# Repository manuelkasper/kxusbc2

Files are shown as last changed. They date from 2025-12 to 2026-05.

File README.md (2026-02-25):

# KXUSBC2 – Internal USB-C charger for the Elecraft KX2

## Introduction

Have you ever forgotten to bring your KX2 charger on a trip, accidentally torn the speaker wires after countless battery removals, or found yourself with a dead phone battery on a summit while the KX2 still had plenty of power? I’ve managed all three. Each time, I wished the KX2 simply had a USB-C port — no more removing the battery, no special charger to pack, and the ability to top up a phone.

External power banks are awkward when operating handheld with the AX1 and may cause QRM. The KXIBC2 option still requires a specific AC adapter, charges very slowly, and cannot supply power to a phone. Perhaps the best solution until now was to bypass the KX2's built-in reverse-power diodes and connect an external USB-C charger. But with all of these solutions, you can forget something at home that you can’t buy on the go.

I prefer fully integrated things that are simple and foolproof to use. So I set out to design an option PCB that installs in place of a KXIBC2 or KXIO2 and adds a bidirectional (dual-role) USB-C port for charging and discharging the internal battery. In homage to Elecraft’s naming convention for KX2 options, I call it the **KXUSBC2** — an unofficial option.

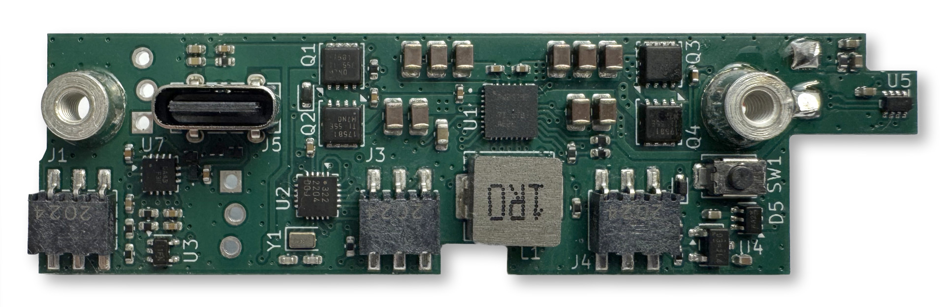
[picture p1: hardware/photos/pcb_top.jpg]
PCB top

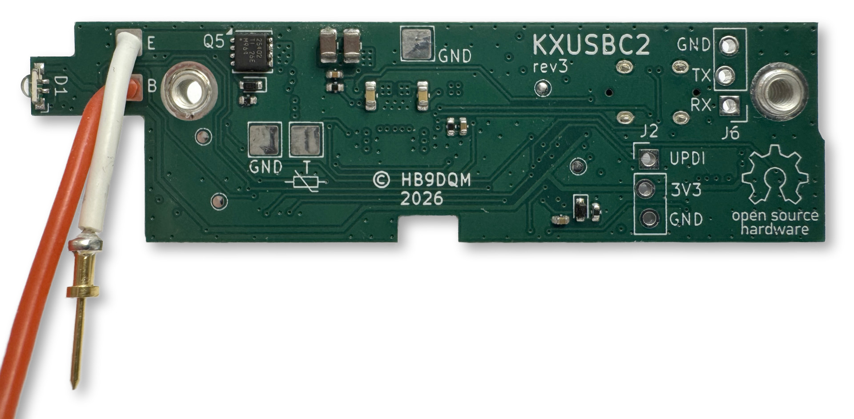
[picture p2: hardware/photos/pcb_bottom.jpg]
PCB bottom


Here is how it looks installed in a KX2, with a custom CNC-machined aluminum side plate for the USB-C port opening:

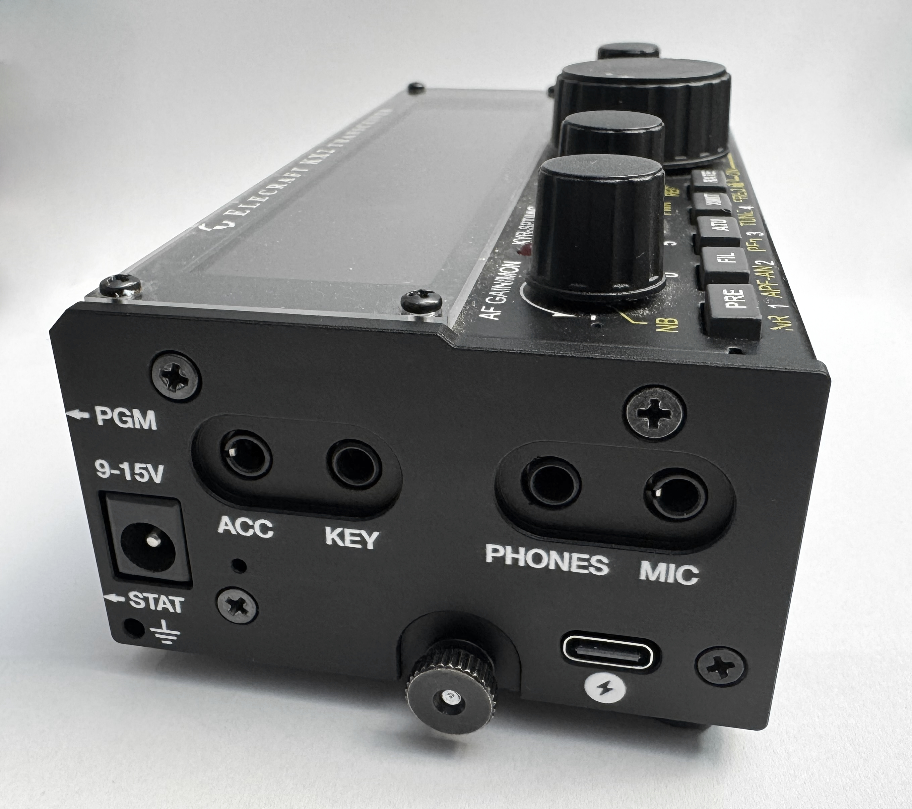
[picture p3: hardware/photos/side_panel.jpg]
KX2 replacement side panel with USB-C port


KXUSBC2 installed, side view

KXUSBC2 installed, top view

## Features

* Adds a bidirectional USB-C charging port to the KX2
* Charges the internal 3S Li-Ion battery at up to 30 W
* Dual-Role Port (DRP/OTG): Can also charge an external device (phone, GPS, HT etc.) through the same USB-C port at up to 30 W (5…15 V)
* Dual input: can charge from USB-C or DC jack
* Supports PD 3.0, QC, BC1.2
* Automatically suspends charging while KX2 is on
* Real-Time Clock (RTC)
* RGB status LED and config button
* Battery temperature monitoring (with thermistor, optional)
* Battery voltage monitor in KX2 menu (like KXIBC2)

## Tech details

* BQ25792 buck-boost battery charger IC
  * 1.5 MHz switching frequency
  * Quad external power MOSFETs for input switching
* FUSB302B USB-C controller
* ATtiny3226 microcontroller
  * Implements the PD protocol stack in firmware
  * Current/voltage limits etc. configurable in EEPROM
  * Config button for basic settings, trigger a PD role swap, reset
  * UPDI debug/programming header
  * Serial debug console header
* RTC emulated in MCU (SPI client), backed by crystal, with temperature compensation
* ~60 µA standby current
* 4-layer PCB
  * Components on both sides (min. 0402)
* Replacement aluminum side panel, CNC milled, anodized and silkscreen printed, with USB-C and button pin hole

For more information and a PDF schematic, see the [hardware notes](hardware/README.md).

## Installation

Installing the KXUSBC2 is quite simple, and similar to the procedure for the KXIBC2. See the [User Guide](USER_GUIDE.md) for details.

## Where to buy

While it is possible to have the board and side panel manufactured by a PCB/CNC service like JLC based solely on the design files in this repository, this is not economically viable at very small quantities due to the setup and overhead costs.

Online shops that sell the KXUSBC2 kit:

* [g7ufo.radio Shop](https://shop.g7ufo.radio/products/kxusbc2)

If you are interested in selling the KXUSBC2 in your shop and having it listed here, please contact me.

Another option (for people who have some experience ordering and working with PCBs) would be to do group buys, e.g. within a club/association. All information required to do this can be found in the [hardware documentation](hardware/README.md).

I am not selling the KXUSBC2 myself, so please do not send me emails with purchase enquiries.

## Firmware updates and configuration

There is a web-based programmer at https://manuelkasper.github.io/kxusbc2/programmer/ that can flash firmware updates and allows easy UI-based configuration of the various settings (current limits etc.). All that is required is a simple UPDI adapter (essentially a USB-to-Serial TTL level adapter) and a browser that supports the Web Serial API.

## Development

The schematic/PCB was designed with KiCad, and the firmware was written to be compiled with AVR-GCC. See the [hardware notes](hardware/README.md) and [firmware notes](firmware/README.md) for details.

## Current state of the project

The PCB has gone through three revisions and is now at rev3, which is considered to be production-ready. rev2 boards have been tested by seven beta testers around the world, and all have worked on first try. The firmware is considered to be complete. See the issues page for any open issues or ideas for future revisions.

### Disclaimer

You are using the KXUSBC2 at your own risk; I won't take responsibility if your KX2, phone, charger, battery, etc. get fried due to this board, your house burns down, or if you unexpectedly end up with an empty battery. You might lose your warranty on the KX2 by using this board.

Elecraft ® is a registered trademark of Elecraft, Inc. This project is not affiliated with or endorsed by Elecraft.

### License

© 2025-2026 Manuel Kasper HB9DQM (mk@neon1.net).

This source describes Open Hardware and is licensed under the CERN-OHL-W v2.

You may redistribute and modify this documentation and make products using it under the terms of the CERN-OHL-W v2 (https:/cern.ch/cern-ohl). This documentation is distributed WITHOUT ANY EXPRESS OR IMPLIED WARRANTY, INCLUDING OF MERCHANTABILITY, SATISFACTORY QUALITY AND FITNESS FOR A PARTICULAR PURPOSE. Please see the CERN-OHL-W v2 for applicable conditions.

Source location: https://github.com/manuelkasper/kxusbc2



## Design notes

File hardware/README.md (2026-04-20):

# Hardware notes

## Schematic

Designed with KiCad.

**[PDF version of the schematic](pcb/kxusbc2.pdf)** for quick viewing (may not be the most recent version).

## PCB

### Specifications

* 4 layers
* FR-4
* 1 mm thickness
* 1 oz copper on all layers (including internal)

The design around the BQ25792 with its inductor and capacitors follows the guidelines given in the datasheet, and takes the EVM design as a basis. However, due to space constraints and the oblong shape, some compromises in the PCB layout had to be made: the BQ25792 has been rotated 180° relative to the reference design, making the switching nodes slightly longer and closer to other traces. Care was taken to keep them isolated from other traces by intermediate ground plane layers.

### JLCPCB order settings

When ordering from JLCPCB, the files located in [pcb/jlcpcb/production_files](pcb/jlcpcb/production_files) can be uploaded directly. The following settings should be selected in the order process:

#### PCB

* Layers: 4
* Dimensions: 69 x 19 mm (will be increased automatically for edge rails)
* PCB Thickness: 1.0 mm
* Material: FR4
* Surface Finish: LeadFree HASL or ENIG
* Outer Copper Weight: 1 oz
* Inner Copper Weight: 1 oz (!)
* Via Covering: Plugged

#### PCB Assembly

* PCBA Type: Standard
* Assembly Side: Both Sides
* Edge Rails/Fiducials: Added by JLCPCB
* Depanel boards & edge rails before delivery: Yes

## Side panel

### Specifications

* Aluminum 6061
* Bead-blasted, hardcoat-anodized, and silkscreened

## Kit components

A full KXUSBC2 "kit" requires the following components:

* KXUSBC2 PCB, assembled on both sides
* Custom side panel
* 3 x Receptacle (unless assembled by PCB factory)
  * TE Connectivity 2307725-3
  * DigiKey [17-2307725-3CT-ND](https://www.digikey.com/en/products/detail/te-connectivity-amp-connectors/2307725-3/11503286)
* 2 x Standoff M2.5 3 mm height (unless assembled by PCB factory)
  * Würth Electronics 9774030151R
  * DigiKey [732-7083-1-ND](https://www.digikey.com/en/products/detail/würth-elektronik/9774030151R/5320626)
* Thermal pad 10x6 mm, 4 mm height
* Stranded silicone insulated wires, AWG 22, red/white 60 mm ea.
* 2 x Solder pin
  * Mill-Max 3132-0-00-15-00-00-08-0
  * DigiKey [ED90540-ND](https://www.digikey.com/en/products/detail/mill-max-manufacturing-corp/3132-0-00-15-00-00-08-0/413214)
* 2 x Solder receptacle
  * Mill-Max 8827-0-15-15-16-27-04-0
  * DigiKey [ED1304-ND](https://www.digikey.com/en/products/detail/mill-max-manufacturing-corp/8827-0-15-15-16-27-04-0/4440738)
* Heat shrink tube 2.5 x 15 mm
* Thermistor (optional)
  * NTC 10k
  * DigiKey [2259-RH18-6Y103FB-075-S-ND](https://www.digikey.com/en/products/detail/mitsubishi-materials-u-s-a-corporation/RH18-6Y103FB-075-S/14308046)

## Cost

Most of the parts are relatively low cost, and the board was designed so that it can be produced and assembled by low-cost services like JLCPCB, with almost all passive components from the “Basic” component selection, which doesn't incur component-loading fees. Most components are on the top side, but due to space constraints, some had to be placed on the bottom side as well. Traces, via holes etc. are fairly large to avoid precision PCB costs.

The total BOM at qty. 10 is around $30/pc. (including PCB production and assembly of both sides), plus $12/pc. for the CNC milled, anodized and silkscreen printed side panel.

## Efficiency

Conversion efficiency

The graph above is taken from the BQ25792's datasheet. I've done some casual measurements, both using the BQ25792's internal ADC and shunts, and with external power meters, and they agree with the data in the graph: around 95% when charging from 15 V input, and between 85% and 90% from 5 V (depending on the current). There seems to be no problem dissipating the maximum possible loss of around 3 W through the side panel (thermal pad placed between the IC and the panel), and in any case, the charger IC has thermal regulation and shutdown.

## Power connection to the KX2

Like the KXIBC2, the KXUSBC2 is intended to be wired to the “E” and “B” pads on the KX2 RF PCB (under the battery) for connection to the external DC jack and the internal battery jack, respectively. Refer to the [KXIBC2 manual](https://ftp.elecraft.com/KX2/Manuals%20Downloads/E740370-B5,%20KXIBC2%20manual.pdf) for details.

Wire lengths, measured from the pad on the KXUSBC2 to the tip of the connector pin attached to the wire: E 28 mm, B 40 mm.

Receptacle pins for soldering to the KX2 PCB, probably also used by Elecraft for factory installation: Mill-Max 8827-0-15-15-16-27-04-0. Mating pin for crimping or soldering to wire: Mill-Max 3132-0-00-15-00-00-08-0 (for 22-24 AWG).

The PCB trace resistance between the “B” pad on the RF PCB and the central pin on the internal battery connector was measured to be around 5 mΩ (4T/Kelvin measurement). So although the pad/trace was probably not intended for this much current, it should have no problems handling 3 A.

The ground connection is via a single header pin rated for 2 A only. However, the standoffs with which the board is mounted to the side panel are grounded too. The coating/anodizing of the side panel should be stripped on the backside around the mounting holes, and along the bottom part where it meets other metal case parts (like the original side panel). This will provide a low-impedance ground connection through the side panel. Mounted this way, the resistance between the GND pad near the top edge of the backside of the KXUSBC2 PCB and the shaft of the battery DC plug was measured to be around 10 mΩ (4T/Kelvin measurement).

## Supported battery types

The charger has been designed for 3S Li-Ion batteries with a charging voltage of 12.6 V and a capacity of around 3000 mAh. The charging/discharging current limits can be changed in the EEPROM if smaller or larger batteries are used. Always use batteries with built-in protection and balancing circuits.

### Using 4S LiFePO₄ batteries

It is also possible to use 4S LiFePO₄ batteries. The charging voltage limit needs to be adjusted in the EEPROM. It is recommended to stay a bit below the limit enforced by the battery's protection circuit. Otherwise, when this voltage is reached during charging, the BMS may react by disconnecting the battery, causing the charging voltage to overshoot. This will manifest itself in a fault condition (red blinking LED), as the charger will detect an over voltage event. Usually 14.2 V is a good upper limit (e.g. some EREMIT batteries cut off at 14.2 V or even slightly below that).

## RTC

Some people like to use the clock provided by the KXIO2/KXIBC2 options for logging. The RTC chip that Elecraft uses (PCF2123) is obsolete, and the successors use a different register mapping that would require modifications to the KX2 firmware. As the MCU has spare capacity, I opted to use its internal RTC instead, emulating the few SPI commands that the KX2 uses to read/write the time in firmware. The RTC is clocked by a 32.768 kHz crystal, and the microcontroller consumes extremely little power for keeping the clock running.

The firmware automatically applies a temperature compensation, and one can also calibrate the clock using the KX2's "RTC ADJ" menu as usual.

Unlike the KXIO2/KXIBC2, the KXUSBC2 does not include a supercapacitor to keep the clock running during short power outages while swapping the battery. Having the KXUSBC2 installed means that most people probably won't need to swap out the battery anymore.

The KX2 uses an SPI frequency of 1 MHz (mode 0), and the delay between asserting RTC_CS (active high) and the beginning of the SPI transmission is about 10 µs.

## Battery monitoring

The KXUSBC2 includes a similar circuit to the one on the KXIBC2 that allows the KX2 to display the actual battery voltage in the menu. It works by dividing down the battery voltage and buffering it with an op-amp before passing it to the microcontroller in the KX2. The “KXIBC2” menu option must be set to “NOR” in the KX2's configuration menu for this to work.

Of course, the KXUSBC2 itself knows all voltages and currents flowing through it precisely, but it has no way to display those values on the KX2's display, as we cannot modify the firmware.

## QRM

A charger like this is somewhat akin to a 10 W PA amplifying a 1.5 MHz square wave into a low-pass filter. Having that right inside a sensitive HF rig, and even electrically connected to it, one might expect QRM mayhem. I thought so too, and thus the firmware defaults to automatically suspending charging while the KX2 is on, so one can still use an external power supply to power the KX2 while operating, without any QRM from the charger.

I did some lab testing with a dummy load connected to the KX2. Result: while charging the KX2 at 28 W from a 15 V PD source, I noticed that the noise floor increased from S0 to around S1 on 80-10m (preamp on). The only really strong signal that I could find in amateur bands was the 9th harmonic of the switching frequency, which varied around 9 * 1.55 = 13.95 MHz and 9 * 1.58 = 14.22 MHz in my test (the charger IC uses an RC oscillator), resulting in S7 QRM in a range of about 10 kHz somewhere in the lower half of the 20m band. Results in reverse mode (charging an iPad at 28 W) were similar.

Not wanting my concoction to cause excessive spurious emissions through the KX2's antenna port, I had a look with a spectrum analyzer. I am by no means an expert in this domain, but according to ETSI EN 301 783 clause 5.2.3, the limit for spurious emissions at the antenna port of an amateur radio device in standby mode is -57 dBm in the frequency range of 0.15 to 1000 MHz.

#### Test conditions
KX2 in off mode (ATU set to bypass before turning off), internal 3S battery charged to around 80%. KX2 antenna port connected directly to spectrum analyzer with 0.5 m LMR 240 cable. Spectrum analyzer set to peak detector mode to capture the worst-case scenario (the standards document is not entirely clear about which detector to use).

### Charging at 5 V @ 2.2 A

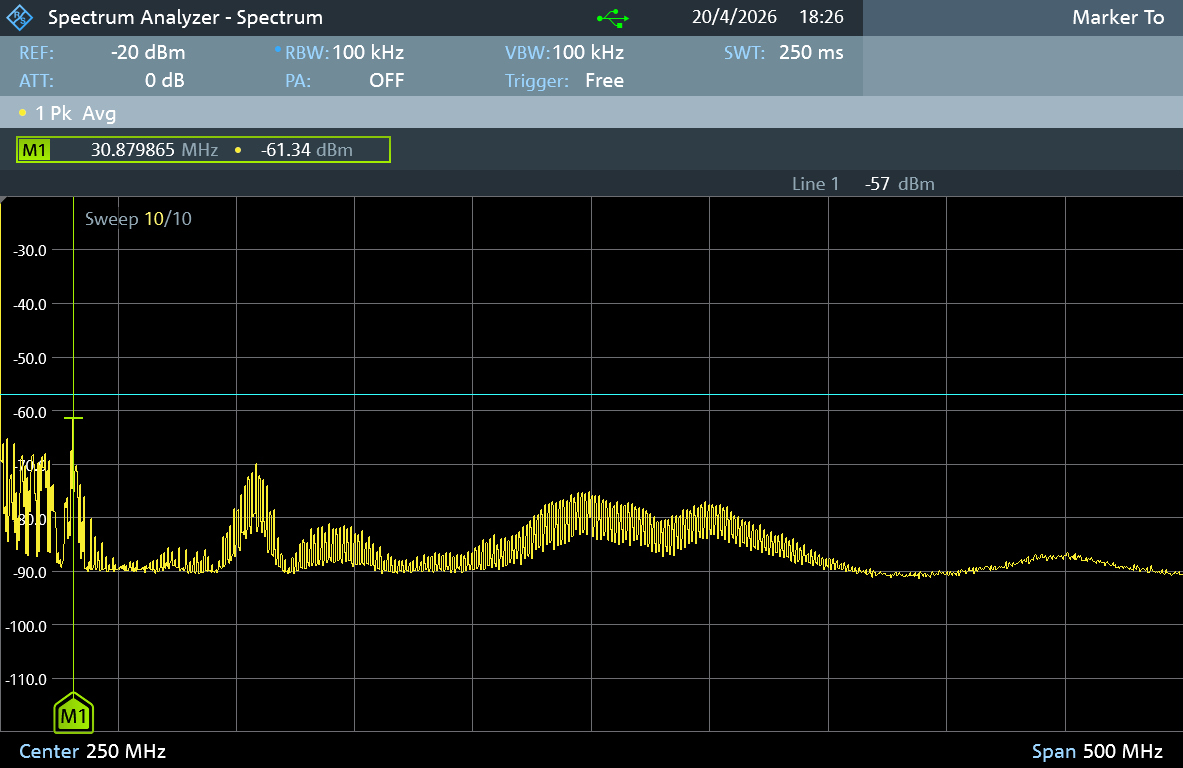
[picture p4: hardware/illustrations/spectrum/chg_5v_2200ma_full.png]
Full spectrum when charging at 5 V @ 2.2 A


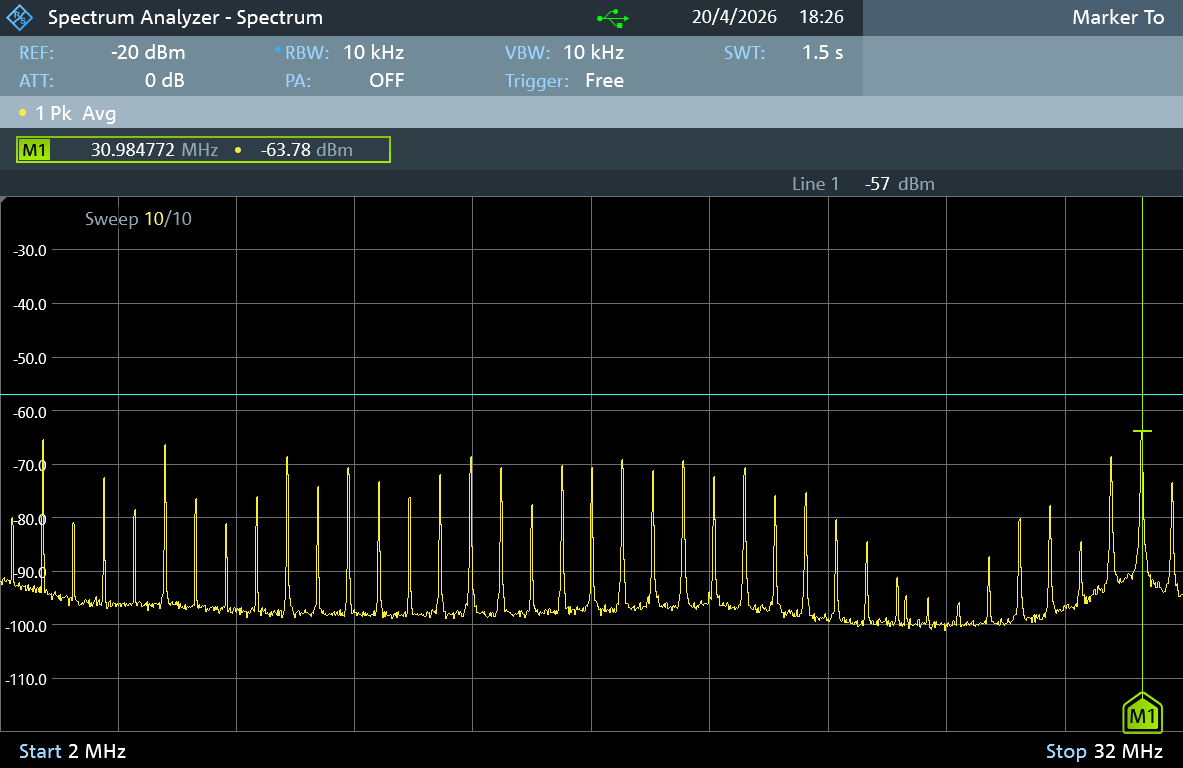
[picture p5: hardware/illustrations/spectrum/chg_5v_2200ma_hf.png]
HF spectrum when charging at 5 V @ 2.2 A


### Charging at 15 V @ 1.6 A

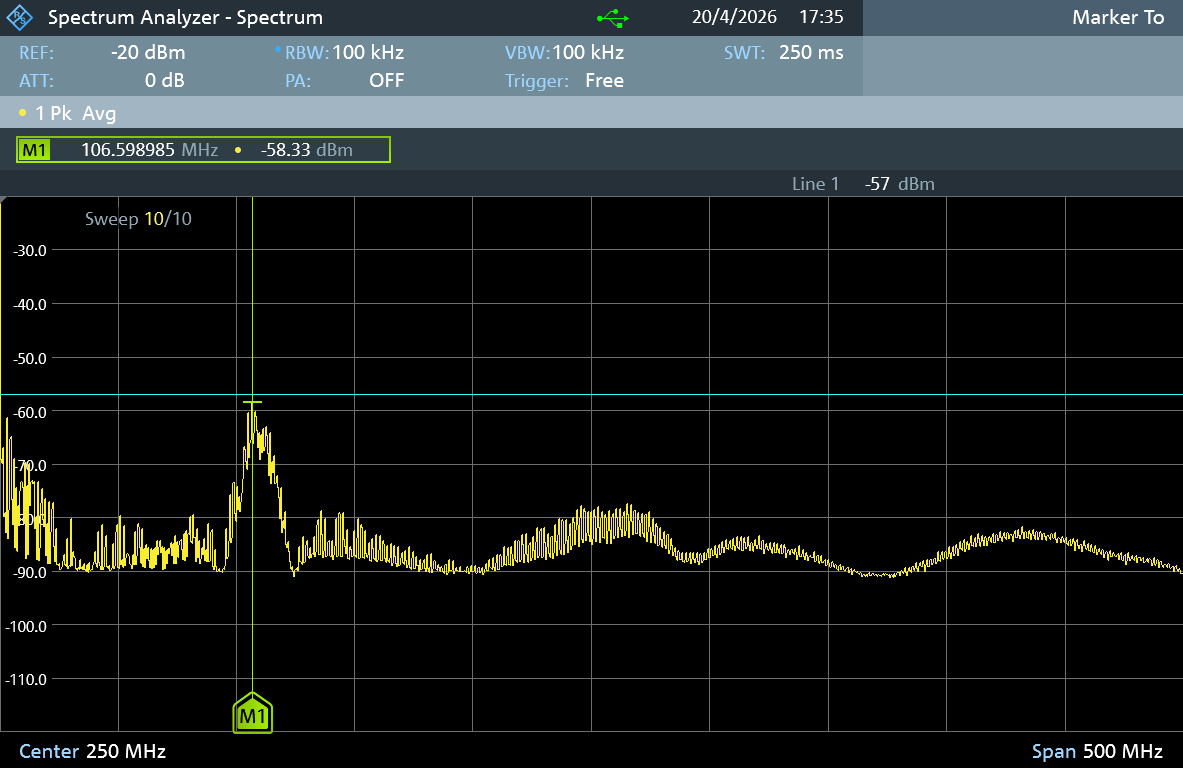
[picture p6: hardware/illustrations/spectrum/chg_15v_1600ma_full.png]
Full spectrum when charging at 15 V @ 1.6 A


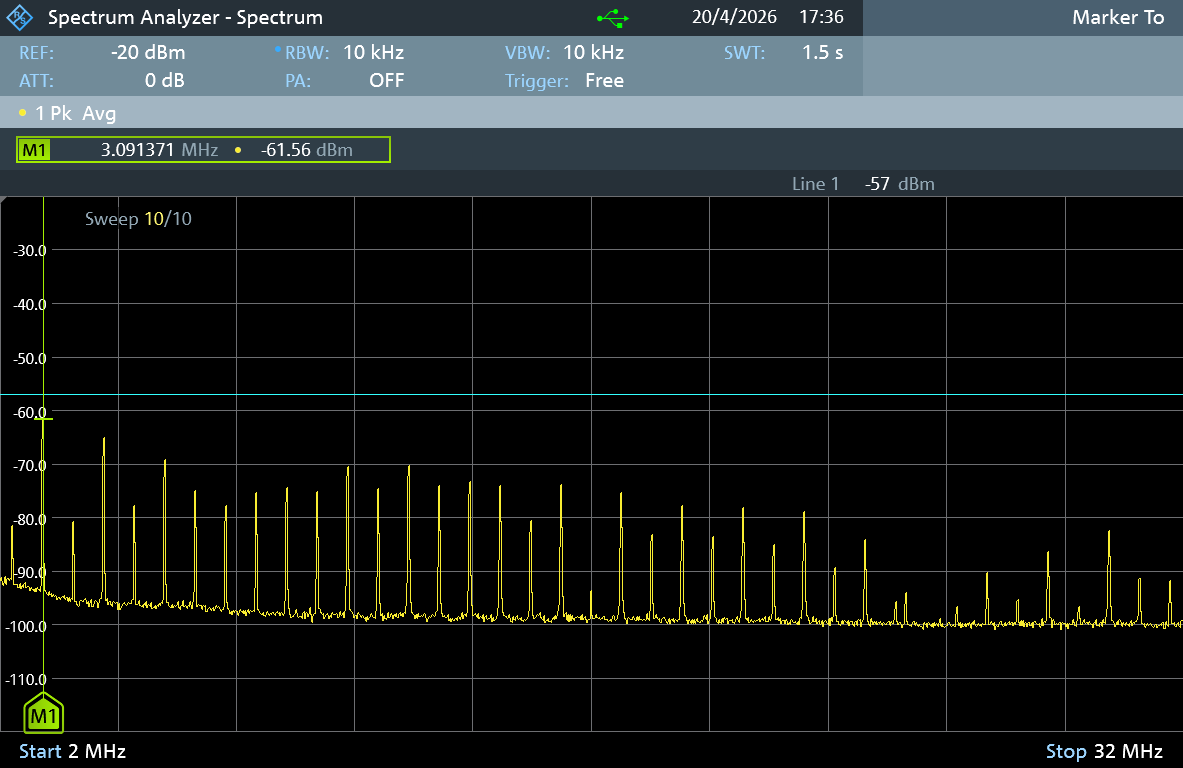
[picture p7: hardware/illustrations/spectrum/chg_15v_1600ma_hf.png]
HF spectrum when charging at 15 V @ 1.6 A


### Discharging at 5 V @ 3 A

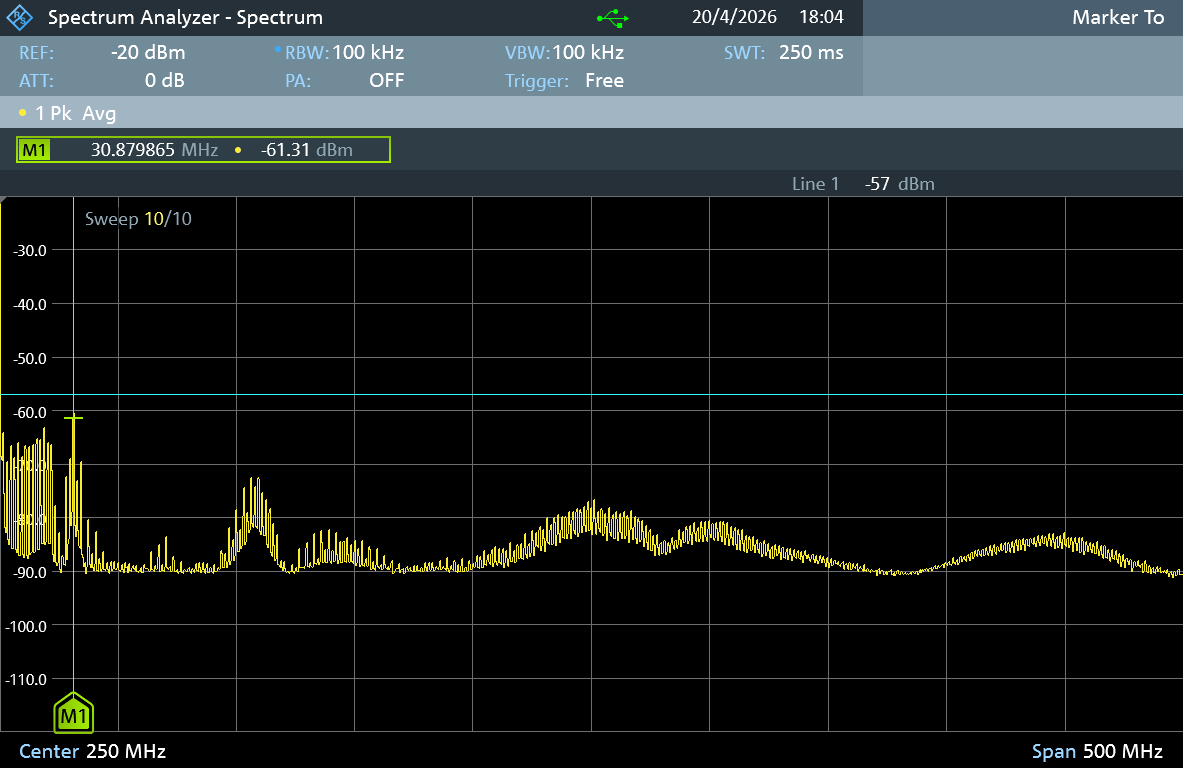
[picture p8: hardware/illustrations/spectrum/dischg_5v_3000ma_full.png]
Full spectrum when discharging at 5 V @ 3 A


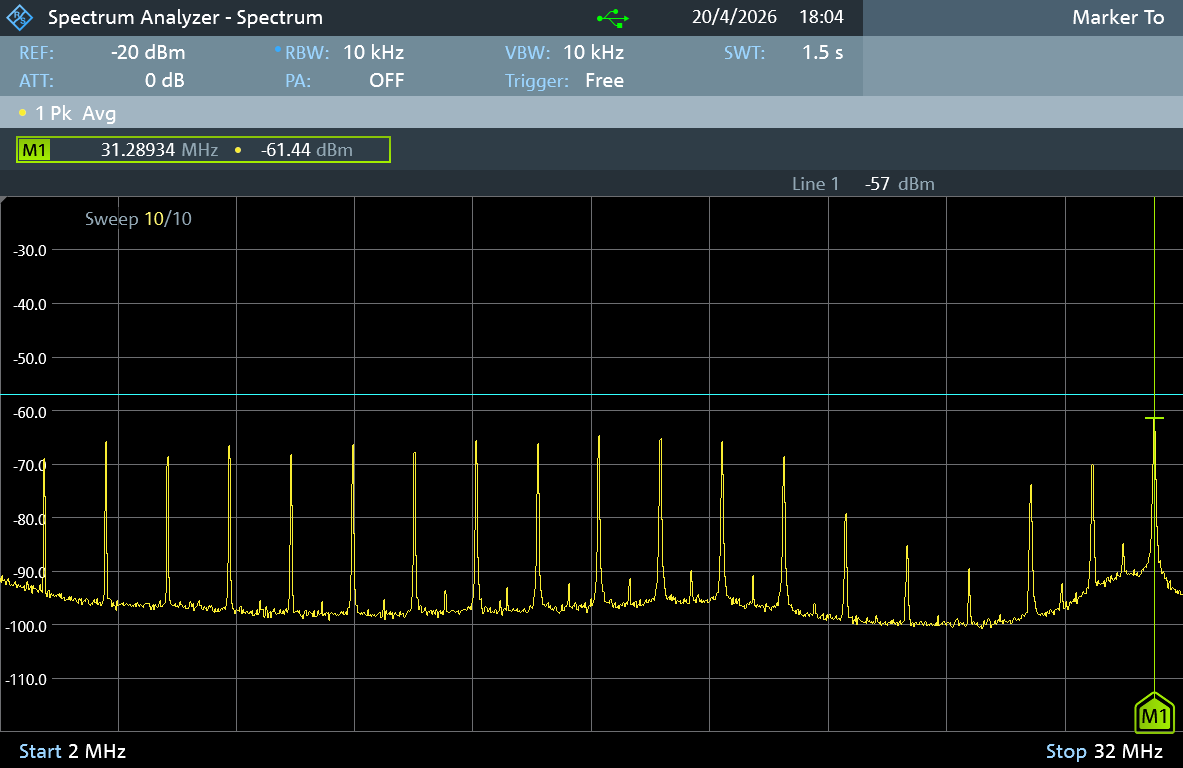
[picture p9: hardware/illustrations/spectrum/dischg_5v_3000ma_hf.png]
HF spectrum when discharging at 5 V @ 3 A


### Discharging at 9 V @ 3 A

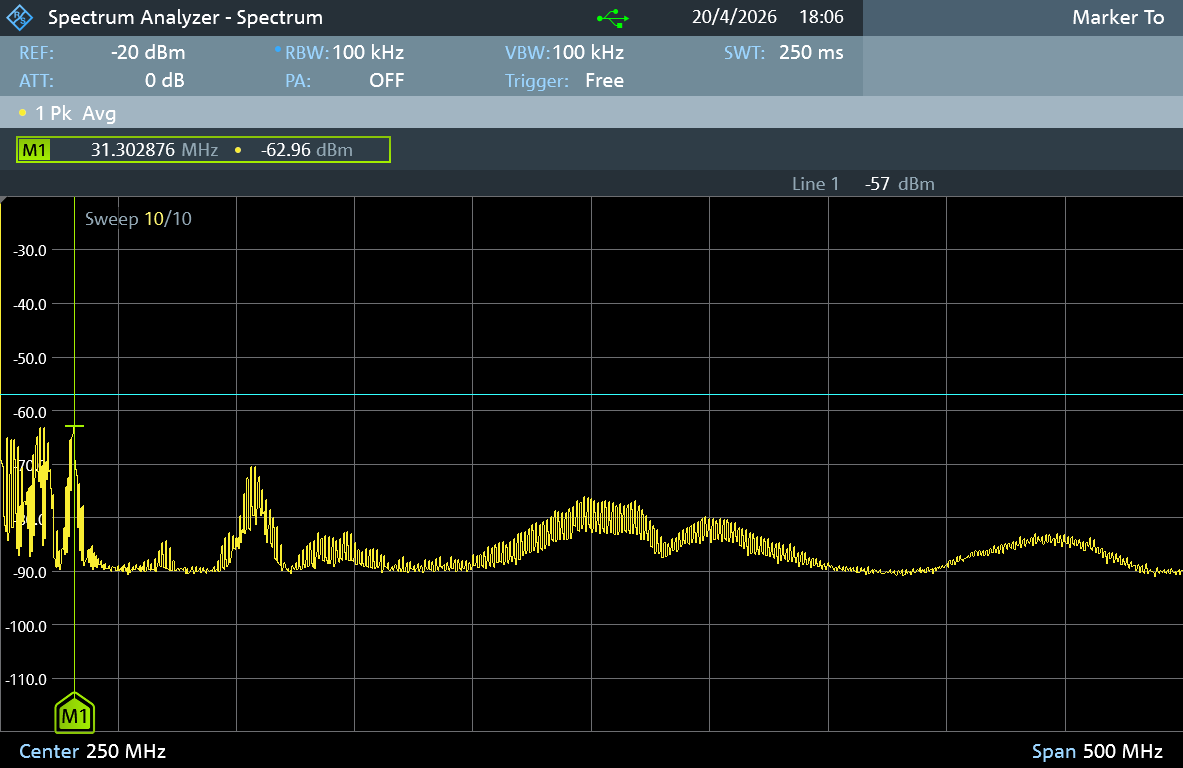
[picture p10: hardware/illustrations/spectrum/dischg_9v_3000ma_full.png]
Full spectrum when discharging at 9 V @ 3 A


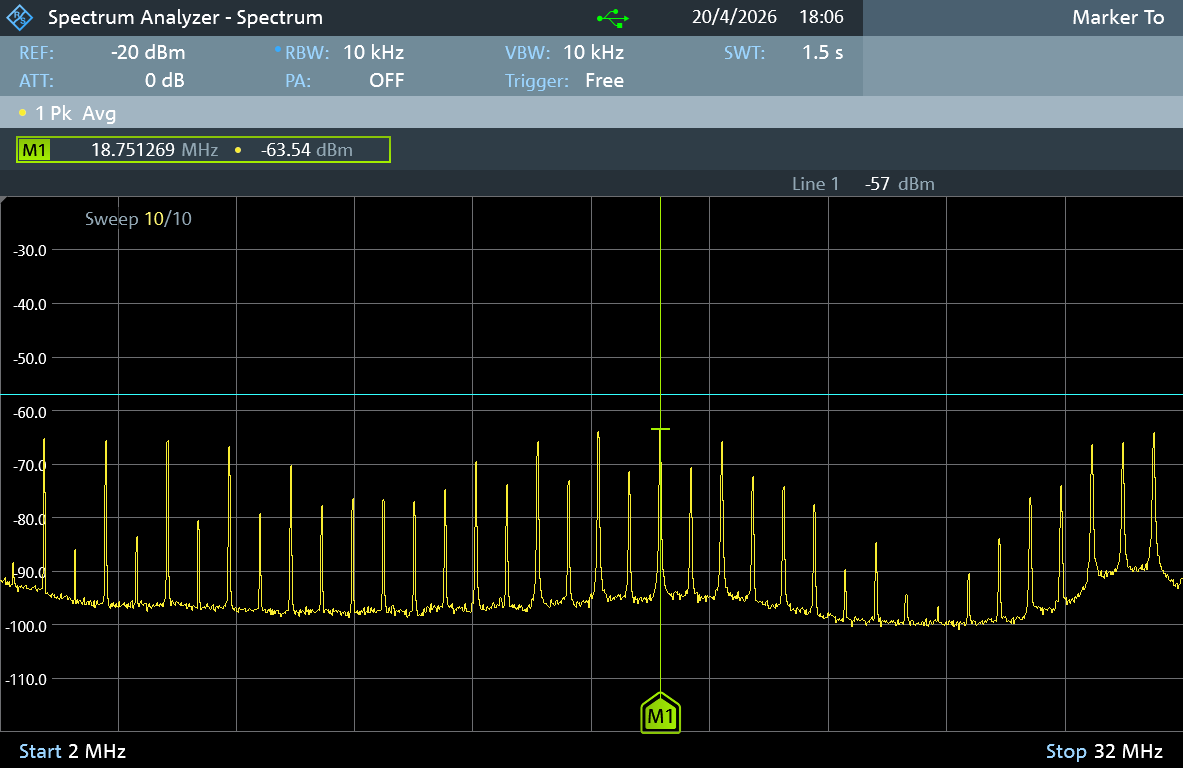
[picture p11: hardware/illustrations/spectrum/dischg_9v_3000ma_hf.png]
HF spectrum when discharging at 9 V @ 3 A


### Discharging at 12 V @ 2.5 A

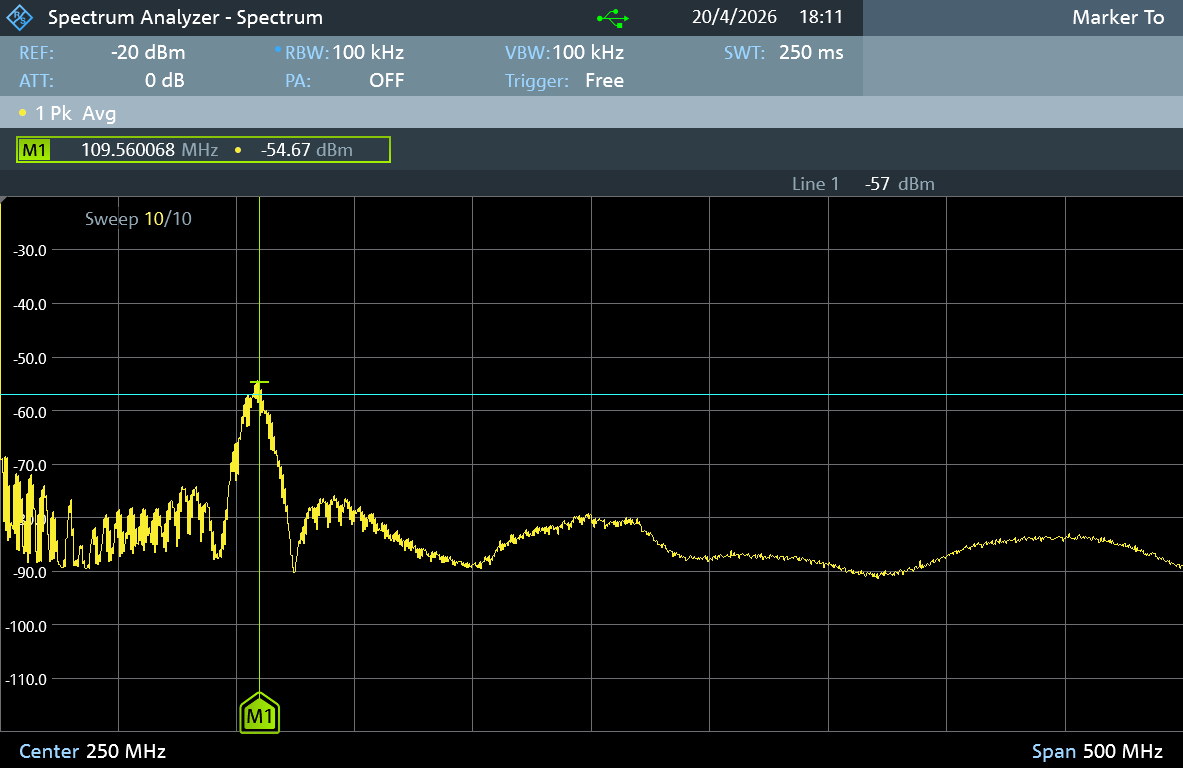
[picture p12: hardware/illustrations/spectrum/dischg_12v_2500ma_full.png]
Full spectrum when discharging at 12 V @ 2.5 A


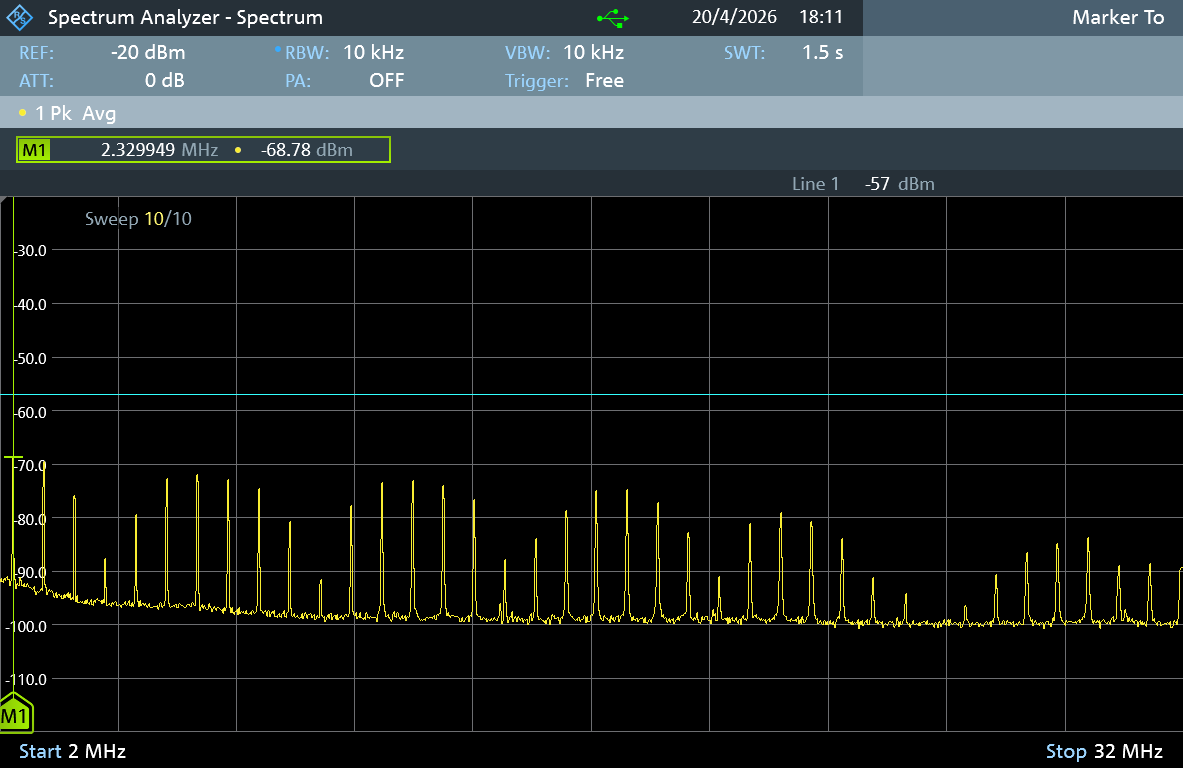
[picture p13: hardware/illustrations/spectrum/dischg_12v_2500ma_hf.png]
HF spectrum when discharging at 12 V @ 2.5 A


### Discharging at 15 V @ 2 A

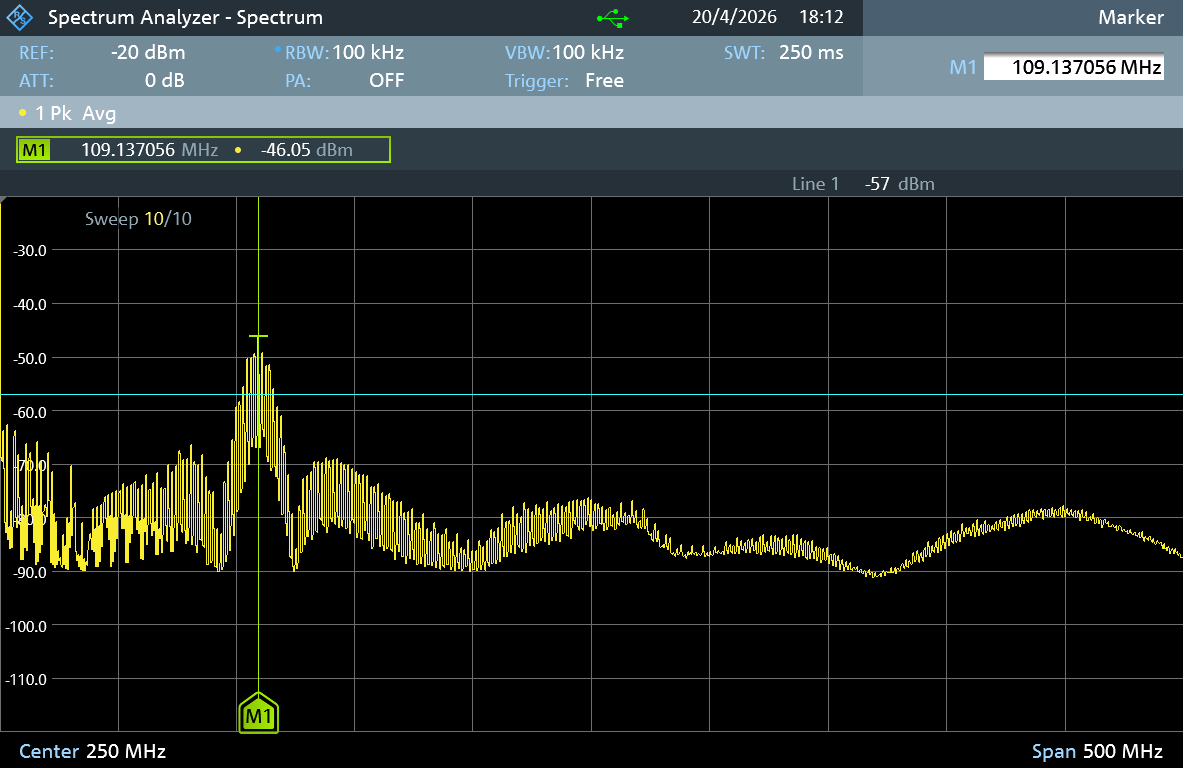
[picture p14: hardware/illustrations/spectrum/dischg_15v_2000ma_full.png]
Full spectrum when discharging at 15 V @ 2 A


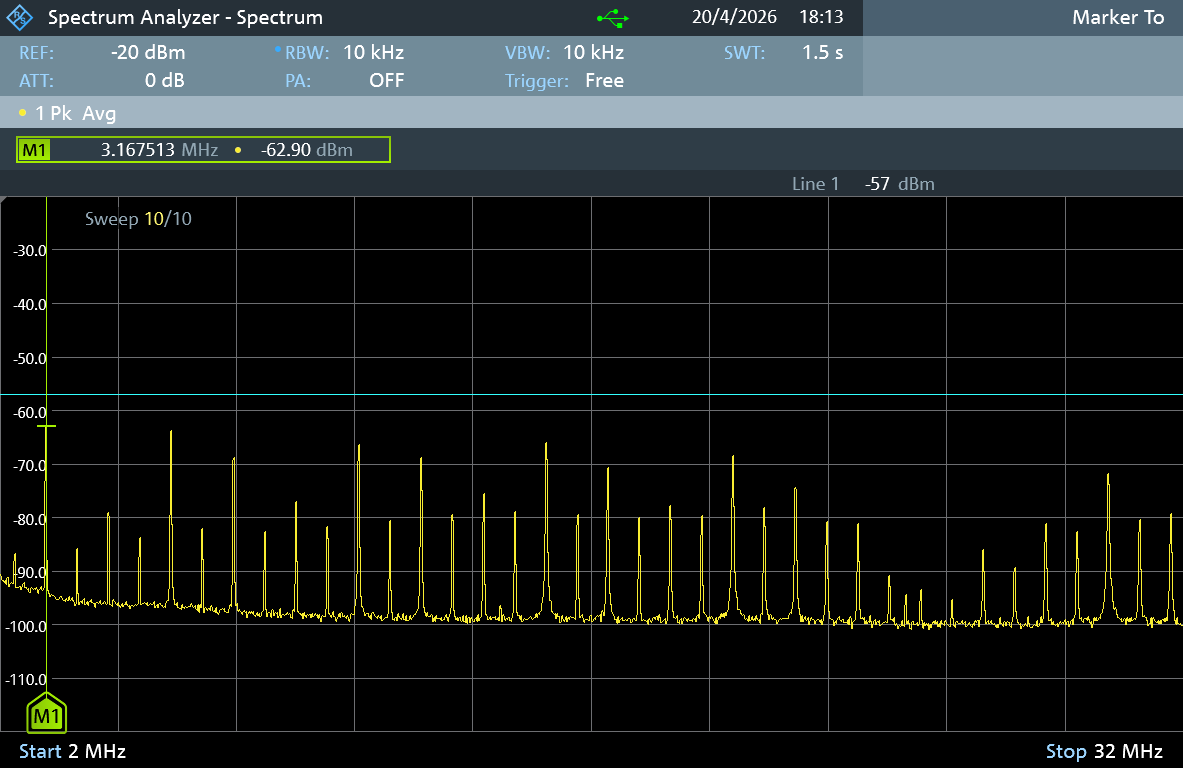
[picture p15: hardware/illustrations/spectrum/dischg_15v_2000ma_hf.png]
HF spectrum when discharging at 15 V @ 2 A


### Summary

When charging at typical power levels (15 V @ 1.6 A was the highest input current encountered during my tests with the maximum battery current set to the default of 2 A), the -57 dBm limit is respected, and also when discharging at typical voltages/currents for an attached smartphone. Only when discharging at both high voltages and high current (12 or 15 V at 2 A) are there spurs around 100 MHz that exceed the limit. It is thus recommended to disconnect the antenna from the KX2 when fast charging external devices. Alternatively, reducing the current to 1.5 A @ 12 V or 1 A @ 15 V also reduces those spurs to below the limit.

For comparison, here is the spectrum at the antenna port of a KX2 in RX mode (no KXUSBC2 installed) with the pre-amp on and the frequency set to 14.333 MHz:

### KX2 spectrum in RX mode (no KXUSBC2 installed)

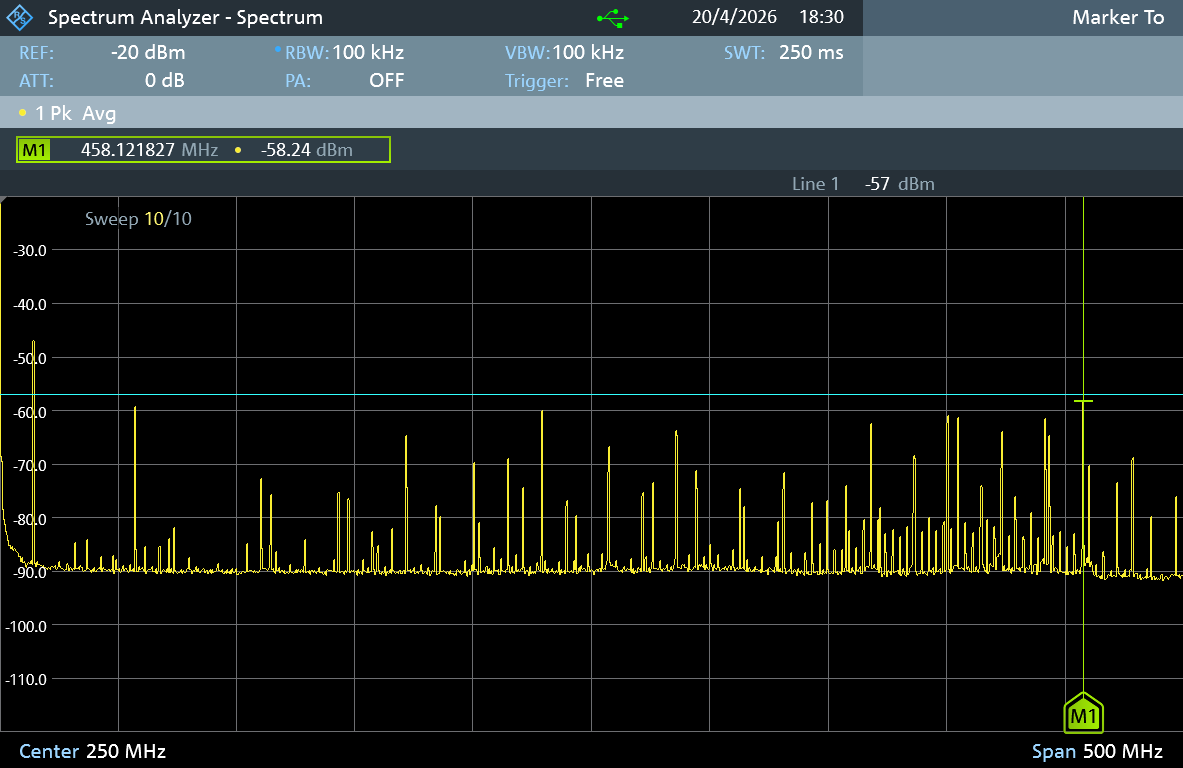
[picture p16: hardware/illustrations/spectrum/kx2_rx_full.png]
Full spectrum with KX2 in RX mode, without KXUSBC2 installed


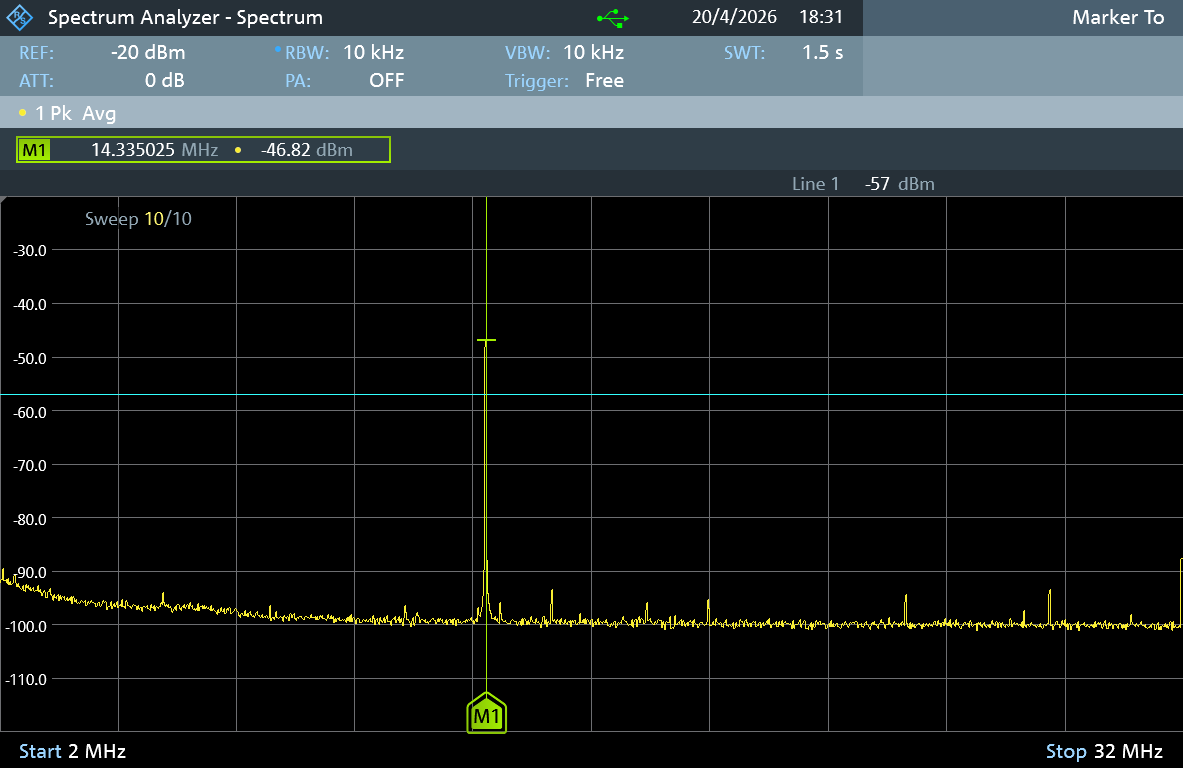
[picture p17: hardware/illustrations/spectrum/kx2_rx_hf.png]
HF spectrum with KX2 in RX mode, without KXUSBC2 installed


### Empirical test on summit with EFHW

Finally, to check the situation that interests the SOTA activator the most, I did a quick empirical test on a summit in a typical setup, with a 40/30/20m EFHW connected to the KX2 in SSB mode. Then I tried charging my iPhone at 10 W (9 V) from the KXUSBC2, and in a separate test, charging the KX2's battery from an external power bank at 18 W (12 V) while operating (auto-suspend feature disabled). In both cases, I could not discern a difference in noise floor on 80-20m, despite disconnecting/reconnecting the USB source/sink many times to find out. There were some spurious wandering signals around 14.310 MHz that I could trace to the charger, probably the 9th harmonic mentioned above, which was even higher now because it was cold on the summit.

Needless to say, it is not recommended to transmit while charging (as the PA drawing current from the charger may lead to increased TX noise/spurs), and by default, this situation is not possible anyway.

So to sum it up: QRM doesn't seem to be a big issue, even if you're charging while operating. And when not charging, the switching converter is completely off, so no QRM.

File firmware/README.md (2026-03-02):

# Firmware notes

The firmware is designed to be built with AVR-GCC.

Prerequisites:

* AVR-GCC toolchain (version 15.2.0)
* AVRDUDE (for programming)

## Build instructions

1. Download release v4.1.2 of the FUSB302 reference code from onsemi (login required): https://www.onsemi.com/design/evaluation-board/FUSB302BGEVB
2. Place the downloaded file `FUSB302 REFERENCE CODE.ZIP` in the root directory of the repository.
3. `sh merge_fsc_pd.sh`
4. Edit `Makefile` and set `PROGRAMMER` and `PORT` as needed.
5. `make` to compile the code.
6. `make flash` to flash the AVR.
7. `make eeprom` to write the default sysconfig settings to the EEPROM.
8. `make fuses` to program the fuses.

`DEBUG` should be set to 0 for release builds, otherwise standby consumption will increase (periodic debug status output, charger ADC active for measurements etc.). Also note that the PD protocol has quite strict timing requirements, and debug code/output can interfere with that and cause problems during PD negotiation, usually manifesting themselves as hard reset loops.

### Recommended fuse settings

The following settings are applied with `make fuses`:

* BOD level: 2.6 V
* Sample frequency: 1 kHz
* BOD mode in active: sampled
* BOD mode in sleep: sampled

#### AVRDUDE config

```
config bodsleep=bod_sampled
config bodactive=bod_sampled
config bodsampfreq=bod_1khz
config bodlevel=bod_2v6
```

## USB PD support

USB Power Delivery (PD) is a pretty complex specification/protocol that involves sending messages between the source and the sink (over the CC lines of the USB-C connector) to exchange capabilities and negotiate a power profile. Implementing a PD protocol stack from scratch for a DRP (Dual Role Port) would be a major undertaking. With some optimizations, I have succeeded in squeezing the reference code supplied by onsemi (makers of the FUSB302B IC) into the 32 KB flash of the ATtiny3226, and making it work.

The downside is that due to the license, while the reference code may be used freely in conjunction with onsemi chips, it cannot be redistributed. Therefore, this repository does not include the complete firmware source code, and requires downloading the reference code from onsemi and applying a patch with my optimizations before the firmware can be compiled (see instructions above).

### Modifications to the onsemi reference code
The patch included in the repository, `fsc_pd.patch`, which is applied automatically by `merge_fsc_pd.sh`, makes the following changes to the reference code:

- Replaced `FSC_U32` with `FSC_U16` or `FSC_U8` where bigger values would never be used anyway. As the AVR is an 8-bit device, operations with larger integers are expensive in terms of code size, memory usage and execution speed, especially if multiplication or division are involved.
    - This shaves around 1700 bytes from the compiled code size.
- When PD 3.0 support is enabled, devices that send a “Get Source Capabilities Extended” message trigger a hardware bug in the FUSB302B, which doesn't automatically send a GoodCRC for this particular message type.
    - Devices that send such messages then run into a timeout because they don't get the expected GoodCRC, and a hard reset loop ensues.
    - The onsemi reference code has a software workaround for this, enabled by the `FSC_GSCE_FIX` define. It works by sending a manual GoodCRC in software for such messages. As the GoodCRC timeout is 1 ms (tReceive), this has to happen fast.
    - However, there is also a bug in the code enabled by `FSC_GSCE_FIX`. Specifically, it uses the `I_CRC_CHK` interrupt instead of the normal `I_GCRCSENT` to trigger receiving a packet in `PDProtocol.c:ProtocolIdle()`. The latter can also be called from `ProtocolSendingMessage()`, but before making that call, `ProtocolSendingMessage()` already checks if `I_TXSENT` or `I_CRC_CHK` are set, and if either of them is, then it also clears `I_CRC_CHK`. This causes `ProtocolIdle()` to miss the incoming packet, which will only be processed when the next packet comes in – usually too late, so timers expire and hard resets are made. The usual case where this is triggered is when the PD source rejects a request, and doesn't send any further packets. Then the tSenderResponse timeout kicks in, the code issues a hard reset, and this loops forever.
    - The patch comments out the clearing of the `I_CRC_CHK` bit, which does not appear to have negative consequences.
- Increased tSenderResponse to 32 ms (USB PD ECN “Chunking Timing Issue”).
- Fixed case-sensitivity issue in `Port.c`: the onsemi code includes `"fusb30x.h"` but the actual filename is `fusb30X.h`. This had caused compilation to fail on case-sensitive filesystems (Linux).
- Set `TOG_SAVE_PWR` to 3 to reduce standby power consumption.

## Programming/Debugging

The ATtiny3226 has a one-wire UPDI interface for programming and debugging. The KXUSBC2 board provides this on a 3-pin 2.54 mm header on the backside, along with Vcc (3.3 V) and GND. The header doesn't actually need to be soldered – the middle pad is slightly offset/staggered, so one can get a good-enough interference fit by simply sticking a pin header through the holes for a temporary connection to the debugger. Call it a poor man's (or hobbyist-friendly) Tag-Connect 😂 This can be used directly with a NanoUPDI or a UPDI Friend, thus providing a programming solution for less than $10.

There is also a serial interface on a separate 3-pin header (also staggered), wired to the MCU's hardware USART, as UPDI does not support debug console output. Note that the levels there are 3.3 V, not RS-232.

Aside from command line tools like AVRDUDE that can be used to program the firmware and EEPROM, there is also a web-based programmer at https://manuelkasper.github.io/kxusbc2/programmer/ that can flash firmware updates and allows UI-based configuration of the various settings.

## Configuration

The following settings can be set in the EEPROM (see also the definitions in https://github.com/manuelkasper/kxusbc2/blob/main/firmware/src/sysconfig.h):

| Byte offset | Description | Type | Default | Range |
|:---|:---|:-----|:---|:---|
| 0 | Magic value (to detect erased EEPROM) | `uint16` | 0x4355
| 2 | Role | Enum<ul><li>0: SRC</li><li>1: SNK</li><li>2: DRP</li><li>3: TRY_SRC</li><li>4: TRY_SNK</li></ul> | 2: DRP
| 3 | PD mode | Enum<ul><li>0: Off</li><li>1: PD 2.0</li><li>2: PD 3.0</li></ul> | 2: PD 3.0
| 4 | Charging current limit (mA, max. current into battery) | `uint16` | 2000 | 50…5000
| 6 | Charging voltage limit (mV, termination voltage for CV phase) | `uint16` | 12600 | 10000…18800
| 8 | DC input current limit (mA, from DC jack) | `uint16` | 3000 | 100…3300
| 10 | OTG current limit (mA, output to USB) | `uint16` | 3000 | 120…3320
| 12 | Discharging voltage limit (mV, minimum battery voltage for OTG mode) | `uint16` | 9000 |
| 14 | OTG voltage headroom (mV, will be added to output voltage) | `uint16` | 100 | 0…500
| 16 | Allow charging while rig is on | `bool` | 0
| 17 | Enable thermistor | `bool` | 0
| 18 | User RTC offset (ppm, set in KX2 RTC ADJ menu) | `int16` | 0 | -278…+273

**Note that the AVR is a little endian platform**, e.g. the value 3000 would be represented as 0xB80B in EEPROM.

The OTG voltage headroom can be used to compensate for losses in the MOSFETs, PCB traces, cable etc.

### User Row

The MCU has a special EEPROM section called User Row, which is not erased in case of a Chip Erase command. This is different from the normal EEPROM, which is erased, unless the EESAVE fuse is programmed.

The User Row is currently used to store a factory-calibrated RTC offset, so that it is not inadvertently erased.

| Byte offset | Description | Type | Default | Range |
|:---|:---|:-----|:---|:---|
| 0 | Magic value (to detect erased User Row) | `uint16` | 0x5255
| 2 | Factory RTC offset (ppm) | `int8` | 0 | -127…127

## RTC emulation

The firmware acts as an SPI slave/client, emulating PCF2123-style registers to the KX2 firmware. Only the set of registers actually used by the KX2 firmware is implemented. The RTC peripheral of the MCU is clocked by an external 32.768 kHz crystal.

A fixed offset (in ppm) can be programmed in the User Row of the MCU to factory calibrate each board.

The KX2 has an "RTC ADJ" menu that lets the user compensate for a clock being too slow or too fast, by setting the number of seconds per day to compensate. The KX2 firmware translates this into a correction value for the PCF2123. The RTC emulation in the KXUSBC2 firmware calculates the equivalent ppm correction (4.34 ppm per unit according to the PCF2123 datasheet, in the "course mode" that the KX2 uses). The value set in the KX2 menu is stored in the EEPROM of the KXUSBC2 so that it is available after a restart, as the KX2 only sends the value when the user changes it.

The RTC emulation also features a temperature compensation. Once a minute, it measures the temperature using the MCU's built-in sensor and calculates an offset according to the temperature coefficient and turnover temperature given in the crystal's datasheet.

The offsets (factory, user and temperature) are added up before being applied to the `RTC.CALIB` register of the ATtiny3226. Positive offsets make the clock run slower, while negative offsets make it run faster. The maximum correction that can be applied in this way is ±127 ppm (about 11 seconds per day). Larger values will be clamped to this range.

## Input priority

The charger uses either the external DC jack input (E pad), or USB, whichever is connected first. If both sources are connected when the charger starts up, it prefers the DC jack input. The charger keeps using the current source as long as it is available, even if another source becomes available. However, if the current source disconnects, the charger switches. For example, if you connect a DC supply while the charger is charging from USB, it will keep using USB. If you then disconnect USB, it will seamlessly switch over to the DC jack input.

## Charge inhibit when rig is on

By default, the firmware suspends charging while the KX2 is on, to avoid any possibility of QRM. This is especially convenient when operating with an external DC power supply at home. Charging resumes as soon as the rig is turned off. Discharging is always possible, even when the rig is on, as the operator can always decide whether or not to plug in a USB-C device to be charged.

The setting can be changed in the EEPROM such that charging is always allowed, regardless of whether the KX2 is on or not.

## LED indications

| State | Color | Style |
|:---|:---|:---|
| Disconnected | off
| Negotiating | green / yellow (*) | blinking 5 Hz
| Charging | green / yellow (*) | pulsing frequency depending on charge current
| Charged | green | steady
| Temperature too high/low | red | steady
| Fault (over-voltage/current, short circuit etc.) | red | blinking 5 Hz
| Fault (battery voltage too low in OTG mode) | red | blinking 2 Hz
| Fault (charger init) | red | 3 x blinking at 2 Hz, followed by 1 s pause
| Fault (EEPROM) | red | 4 x blinking at 2 Hz, followed by 1 s pause
| Rig on (charging inhibited) | magenta | steady
| Discharging (OTG) | blue / cyan (*) | pulsing frequency depending on discharge current

If the thermistor is enabled and the temperature is in the “warm” or ”cool” region (where the current is reduced, but charging continues), the color is yellow (or cyan) instead of green (or blue).

### Charge/discharge speed indication

The LED will pulse faster the higher the current into or from the battery is.

| Battery current | LED pulsing frequency |
|:---|:---|
| < 500 mA | 8.5 s
| 500..999 mA | 2.5 s
| 1000..1999 mA | 1.2 s
| ≥ 2000 mA | 0.8 s

### Low battery during discharge

If the battery voltage drops below the discharging voltage limit set in the EEPROM, discharging will stop, and the LED will blink red. Further attempts to discharge (by disconnecting and reconnecting a sink) will not initiate discharging again, even if the battery voltage has recovered a little in the meantime. The battery must first be recharged, at least for a short time, before discharging is allowed again.

## Button functions

At this time, the following functions are implemented:

* Short press (< 1 second): attempt a PD role swap
  * Can be used, for example, to charge the KX2 from a smartphone that can act as a source (e.g. iPhone)
* Medium press (1…3 seconds): enter config menu (see below)
* Long press (> 3 seconds): system reset

### Config menu

Pressing the button for 1…3 seconds when nothing is connected to the KXUSBC2 (i.e. the LED is off) enters the config menu.

* While in the menu, the LED blinks yellow at 1 second intervals. The number of blinks indicates the current menu item.
* Short pressing advances to the next menu item.
* Medium pressing enters the currently blinking menu item.
  * The LED then blinks blue to show the current setting of the selected menu item.
  * Short pressing changes the setting.
  * Medium pressing leaves the menu item.
* Long pressing leaves the menu and restarts the system with the new settings.

| Menu item # | Description |
|:---|:---|
| 1 | Charging current limit
| 2 | DC input current limit
| 3 | Charge while rig is on
| 4 | Thermistor

#### Menu item 1: Charging current limit

| Value # | Description |
|:---|:---|
| 1 | 500 mA
| 2 | 1000 mA
| 3 | 2000 mA
| 4 | 3000 mA

#### Menu item 2: DC input current limit

| Value # | Description |
|:---|:---|
| 1 | 500 mA
| 2 | 1000 mA
| 3 | 2000 mA
| 4 | 3000 mA

#### Menu item 3: Charge while rig is on

| Value # | Description |
|:---|:---|
| 1 | disable
| 2 | enable

#### Menu item 4: Thermistor

| Value # | Description |
|:---|:---|
| 1 | disable
| 2 | enable

## Connection states

Enum values used by the FSC PD reference code, listed here for convenience to aid in debugging.

| Enum Value | Number |
|:---|---|
| Disabled | 0 |
| ErrorRecovery | 1 |
| **Unattached** | 2 |
| AttachWaitSink | 3 |
| **AttachedSink** | 4 |
| AttachWaitSource | 5 |
| **AttachedSource** | 6 |
| TrySource | 7 |
| TryWaitSink | 8 |
| TrySink | 9 |
| TryWaitSource | 10 |
| AudioAccessory | 11 |
| DebugAccessorySource  | 12 |
| AttachWaitAccessory | 13 |
| PoweredAccessory | 14 |
| UnsupportedAccessory  | 15 |
| DelayUnattached | 16 |
| UnattachedSource | 17 |
| DebugAccessorySink | 18 |
| AttachWaitDebSink | 19 |
| AttachedDebSink | 20 |
| AttachWaitDebSource | 21 |
| AttachedDebSource | 22 |
| TryDebSource | 23 |
| TryWaitDebSink | 24 |
| UnattachedDebSource | 25 |
| IllegalCable | 26 |
| UnattachedSourceOnly  | 27 |

## PD policy states

Enum values used by the FSC PD reference code, listed for convenience here to aid in debugging.

| Enum Value | Number |
|:---|---|
| peDisabled | 0 |
| peErrorRecovery | 1 |
| peSourceHardReset | 2 |
| peSourceSendHardReset | 3 |
| peSourceSoftReset | 4 |
| peSourceSendSoftReset | 5 |
| peSourceStartup | 6 |
| peSourceSendCaps | 7 |
| peSourceDiscovery | 8 |
| peSourceDisabled | 9 |
| peSourceTransitionDefault | 10 |
| peSourceNegotiateCap | 11 |
| peSourceCapabilityResponse | 12 |
| peSourceWaitNewCapabilities | 13 |
| peSourceTransitionSupply | 14 |
| **peSourceReady** | 15 |
| peSourceGiveSourceCaps | 16 |
| peSourceGetSinkCaps | 17 |
| peSourceSendPing | 18 |
| peSourceGotoMin | 19 |
| peSourceGiveSinkCaps | 20 |
| peSourceGetSourceCaps | 21 |
| peSourceSendDRSwap | 22 |
| peSourceEvaluateDRSwap | 23 |
| peSourceAlertReceived | 24 |
| peSinkHardReset | 25 |
| peSinkSendHardReset | 26 |
| peSinkSoftReset | 27 |
| peSinkSendSoftReset | 28 |
| peSinkTransitionDefault | 29 |
| peSinkStartup | 30 |
| peSinkDiscovery | 31 |
| peSinkWaitCaps | 32 |
| peSinkEvaluateCaps | 33 |
| peSinkSelectCapability | 34 |
| peSinkTransitionSink | 35 |
| **peSinkReady** | 36 |
| peSinkGiveSinkCap | 37 |
| peSinkGetSourceCap | 38 |
| peSinkGetSinkCap | 39 |
| peSinkGiveSourceCap | 40 |
| peSinkSendDRSwap | 41 |
| peSinkAlertReceived | 42 |
| peSinkEvaluateDRSwap | 43 |
| peSourceSendVCONNSwap | 44 |
| peSourceEvaluateVCONNSwap | 45 |
| peSinkSendVCONNSwap | 46 |
| peSinkEvaluateVCONNSwap | 47 |
| peSourceSendPRSwap | 48 |
| peSourceEvaluatePRSwap | 49 |
| peSinkSendPRSwap | 50 |
| peSinkEvaluatePRSwap | 51 |
| peGetCountryCodes | 52 |
| peGiveCountryCodes | 53 |
| peNotSupported | 54 |
| peGetPPSStatus | 55 |
| peGivePPSStatus | 56 |
| peGiveCountryInfo | 57 |
| peGiveVdm | 58 |
| peUfpVdmGetIdentity | 59 |
| peUfpVdmSendIdentity | 60 |
| peUfpVdmGetSvids | 61 |
| peUfpVdmSendSvids | 62 |
| peUfpVdmGetModes | 63 |
| peUfpVdmSendModes | 64 |
| peUfpVdmEvaluateModeEntry | 65 |
| peUfpVdmModeEntryNak | 66 |
| peUfpVdmModeEntryAck | 67 |
| peUfpVdmModeExit | 68 |
| peUfpVdmModeExitNak | 69 |
| peUfpVdmModeExitAck | 70 |
| peUfpVdmAttentionRequest | 71 |
| peDfpUfpVdmIdentityRequest | 72 |
| peDfpUfpVdmIdentityAcked | 73 |
| peDfpUfpVdmIdentityNaked | 74 |
| peDfpCblVdmIdentityRequest | 75 |
| peDfpCblVdmIdentityAcked | 76 |
| peDfpCblVdmIdentityNaked | 77 |
| peDfpVdmSvidsRequest | 78 |
| peDfpVdmSvidsAcked | 79 |
| peDfpVdmSvidsNaked | 80 |
| peDfpVdmModesRequest | 81 |
| peDfpVdmModesAcked | 82 |
| peDfpVdmModesNaked | 83 |
| peDfpVdmModeEntryRequest | 84 |
| peDfpVdmModeEntryAcked | 85 |
| peDfpVdmModeEntryNaked | 86 |
| peDfpVdmModeExitRequest | 87 |
| peDfpVdmExitModeAcked | 88 |
| peSrcVdmIdentityRequest | 89 |
| peSrcVdmIdentityAcked | 90 |
| peSrcVdmIdentityNaked | 91 |
| peDfpVdmAttentionRequest | 92 |
| peCblReady | 93 |
| peCblGetIdentity | 94 |
| peCblGetIdentityNak | 95 |
| peCblSendIdentity | 96 |
| peCblGetSvids | 97 |
| peCblGetSvidsNak | 98 |
| peCblSendSvids | 99 |
| peCblGetModes | 100 |
| peCblGetModesNak | 101 |
| peCblSendModes | 102 |
| peCblEvaluateModeEntry | 103 |
| peCblModeEntryAck | 104 |
| peCblModeEntryNak | 105 |
| peCblModeExit | 106 |
| peCblModeExitAck | 107 |
| peCblModeExitNak | 108 |
| peDpRequestStatus | 109 |
| peDpRequestStatusAck | 110 |
| peDpRequestStatusNak | 111 |
| peDpRequestConfig | 112 |
| peDpRequestConfigAck | 113 |
| peDpRequestConfigNak | 114 |
| PE_BIST_Receive_Mode | 115 |
| PE_BIST_Frame_Received | 116 |
| PE_BIST_Carrier_Mode_2 | 117 |
| PE_BIST_Test_Data | 118 |
| dbgGetRxPacket | 119 |
| dbgSendTxPacket | 120 |
| peSendCableReset | 121 |
| peSendGenericCommand | 122 |
| peSendGenericData | 123 |

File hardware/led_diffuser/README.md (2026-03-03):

# LED Diffuser

This helps to diffuse the light from the LED, making it more even and reducing glare. It also helps to protect the LED from damage and the cables from strain.

The LED Diffuser fitted to the KX2

## Printing

This should be printed in PETG or ABS, preferably with a transparent or very light coloured filament.

This is a simple part and can be printed with the default settings for your filament. However, to try and get as clear a print as possible I used the following settings:

- Print as hot as the filament allows.
- No fans (to allow it to cool slowly).
- Infill density: 100%.
- Infill pattern: Straight lines.
- No top/bottom layers.
- No supports or brim required.
- Layer height: 0.1mm.
- Line width: 0.36mm.

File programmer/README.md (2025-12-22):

# KXUSBC2 Programmer

This is a browser-based programming tool for the ATtiny3226 microcontroller on the KXUSBC2. It allows updating the firmware, and changing the EEPROM configuration.

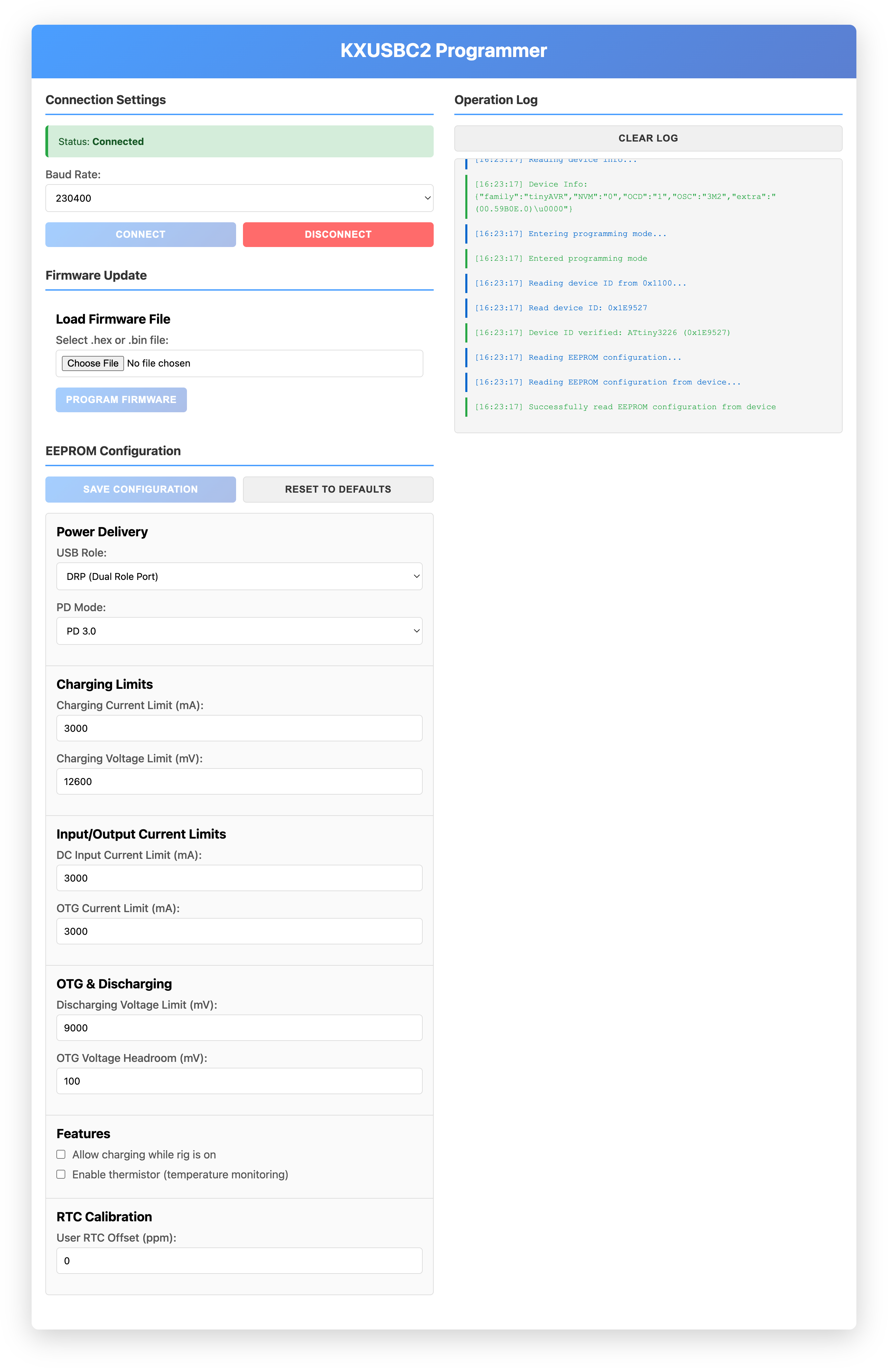
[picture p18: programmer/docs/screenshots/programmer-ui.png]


Prerequisites:

* KXUSBC2
* Simple "serial UPDI" programmer (see below)
* Browser that supports the Web Serial API (Chrome, Edge, Opera)

You can access this programmer directly in your browser, without downloading or building anything, here:

**https://manuelkasper.github.io/kxusbc2/programmer/**

This programmer is based on the more generic [WebUPDI](https://github.com/manuelkasper/webupdi).

## Simple UPDI programmer hardware

The hardware for a UPDI programmer can be very simple and cheap: a USB-to-Serial adapter with TTL levels (3.3 or 5 V depending on the circuit that the AVR is being used in) and a 1k resistor is all that it takes. See for example here:

* UPDI Friend: https://www.adafruit.com/product/5879
* https://github.com/BlackBrix/AVR-Programmer/tree/master/SerialUPDI_Programmer
* https://github.com/umbertoragone/nanoupdi

## Development

### Setup
```bash
npm install
```

### Development Server
```bash
npm run dev
```
This starts a local development server at http://localhost:3000 with hot module reloading.

### Build for Production
```bash
npm run build
```
This generates an optimized production build in the `dist/` directory that can be deployed to a web server.

### Preview Production Build
```bash
npm run preview
```
This starts a local server to preview the production build.

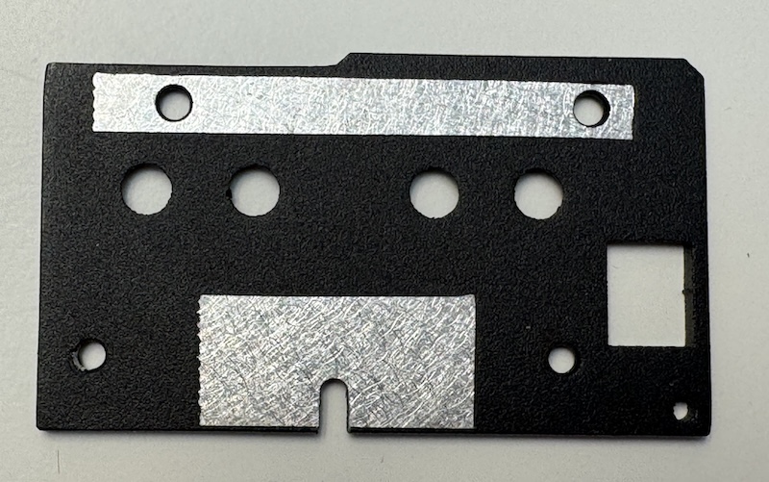
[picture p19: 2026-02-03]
hardware/photos/side_panel_back_original.jpg

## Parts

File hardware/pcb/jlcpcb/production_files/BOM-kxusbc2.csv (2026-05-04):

Comment | Designator | Footprint | LCSC | Quantity
0.1u | C15,C16,C22,C23,C24,C29,C30,C39,C8,C9 | C_0402_1005Metric | C307331 | 10
10.5k | R1 | R_0402_1005Metric | C25850 | 1
100 | R8 | R_0402_1005Metric | C25076 | 1
100k | R12,R17,R18 | R_0402_1005Metric | C25741 | 3
10k | R11 | R_0402_1005Metric | C25744 | 1
10u | C1,C17,C18,C19,C2,C20,C21,C25,C26,C5,C6,C7 | C_0805_2012Metric | C440198 | 12
12V | D2,D3 | D_SOD-523 | C2993013 | 2
1k | R15 | R_0402_1005Metric | C11702 | 1
1n | C12,C13,C14 | C_0402_1005Metric | C1523 | 3
1u | C27,C28,C31,C35,C36,C37 | C_0402_1005Metric | C52923 | 6
2 | R13,R4 | R_0402_1005Metric | C270630 | 2
2.2M | R5 | R_0402_1005Metric | C138015 | 1
220p | C34,C38 | C_0402_1005Metric | C1530 | 2
22p | C32,C33 | C_0402_1005Metric | C1555 | 2
30.31k | R3 | R_0402_1005Metric | C29402 | 1
32.768 kHz | Y1 | Crystal_SMD_2012-2Pin_2.0x1.2mm | C276423 | 1
330 | R10,R9 | R_0402_1005Metric | C25104 | 2
4.7k | R16,R6,R7 | R_0402_1005Metric | C25900 | 3
4.7u | C10 | C_0603_1608Metric | C19666 | 1
4.7u | C11 | C_0402_1005Metric | C23733 | 1
47n | C3,C4 | C_0603_1608Metric | C1622 | 2
5.24k | R2 | R_0402_1005Metric | C25907 | 1
5.6V | D10 | D_SOD-523 | C19077464 | 1
680k | R14 | R_0402_1005Metric | C4131 | 1
APFA3010LSEEZGKQBKC | D1 | LED_Kingbright_APFA3010_3x1.5mm_Horizontal | C5393554 | 1
APH0630T1R0M | L1 | L_APV_APH0630 | C5349700 | 1
ATtiny3226-M | U2 | VQFN-20-1EP_3x3mm_P0.4mm_EP1.7x1.7mm | C3216895 | 1
BAS16TW | D5 | SOT-363_SC-70-6 | C155382 | 1
BAT43XV2 | D4 | D_SOD-523 | C463439 | 1
BQ25792RQMR | U1 | QFN40P400X400X100-29N | C2862876 | 1
CSD17581Q3A | Q1,Q2,Q3,Q4 | VSON-8_3.3x3.3mm_TI_CSD | C2861705 | 4
CSD25402Q3A | Q5 | VSON-8_3.3x3.3mm_TI_CSD | C111356 | 1
Conn_01x03 | J1,J3,J4 | TE_1-2307727-3 | C3322456 | 3
DESD5V0U1BL-7B | D6,D7,D8,D9 | DESD5V0U1BL7B | C1869323 | 4
FUSB302BMPX | U7 | WQFN-14-1EP_2.5x2.5mm_P0.5mm_EP1.45x1.45mm | C132291 | 1
GT-USB-7055AB | J5 | CONN_GT-USB-7055A_GSW | C22383826 | 1
LP5815DRLR | U5 | SOTFL50P160X60-8N | C47262831 | 1
MountingHole_Pad | H1,H2 | Wuerth_9774030151_HS | C5373032 | 2
RT9058-33GV | U4 | SOT-23-3 | C147968 | 1
SW_Push | SW1 | SW_SPST_TS-1088-xR020 | C720477 | 1
TLV9301xDCK | U3 | SOT-353_SC-70-5 | C4366617 | 1

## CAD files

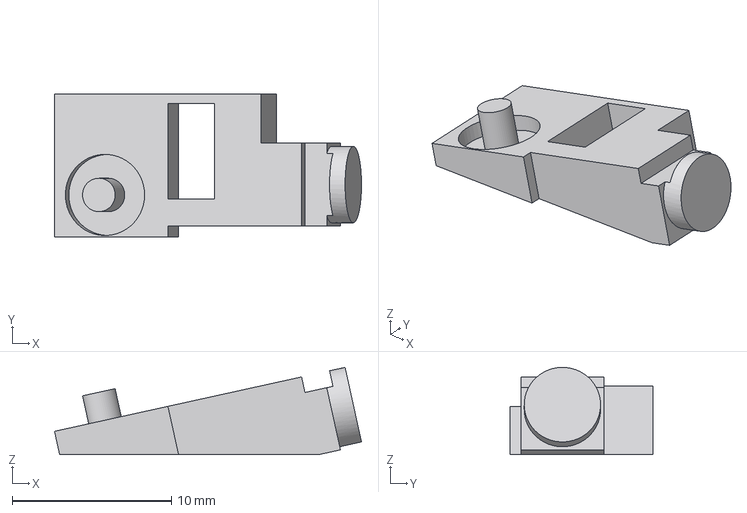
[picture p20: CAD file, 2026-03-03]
hardware/led_diffuser/led_diffuser.step
19.3 x 9.00 x 5.49 mm

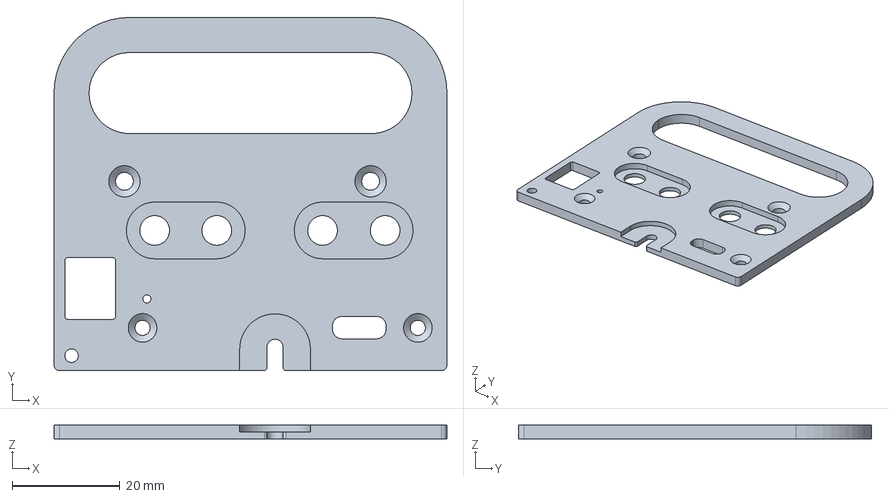
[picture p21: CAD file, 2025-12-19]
hardware/side_panel/side_panel_handles_s.step
72.8 x 65.4 x 2.60 mm

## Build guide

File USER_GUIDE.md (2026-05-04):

# KXUSBC2 User Guide

## Part 1: Hardware Assembly

### ➡️ If you have purchased a ready-made KXUSBC2 kit, this part will already have been completed for you, and you can skip to [Part 2](#part-2-installation-guide).

### Prerequisites

- KXUSBC2 PCB, assembled on both sides
- Replacement left side aluminum panel with USB-C opening
- 2 pcs. mating pins ([Mill-Max 3132-0-00-15-00-00-08-0](https://www.digikey.com/en/products/detail/mill-max-manufacturing-corp/3132-0-00-15-00-00-08-0/413214)) Mating pin
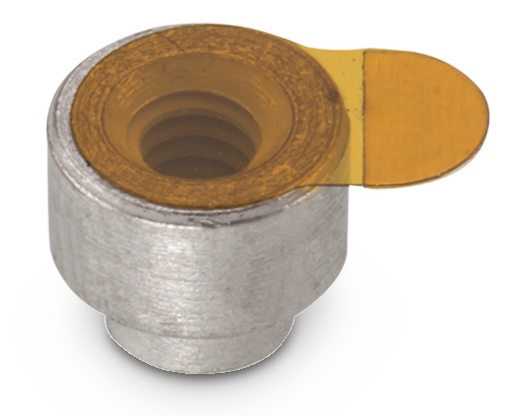
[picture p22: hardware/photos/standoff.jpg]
Standoff
- 2 pcs. standoff M2.5 3 mm height (Würth Electronics 9774030151R, [DigiKey 732-7083-1-ND](https://www.digikey.com/en/products/detail/würth-elektronik/9774030151R/5320626)) 
- White/red silicone wires (22 AWG), ~50 mm ea.
- Kapton tape

**Optional:**
- [3D printed LED diffuser](./hardware/led_diffuser/README.md)

### Preparing the board

#### Soldering the standoffs

1. Place a standoff in a hole on the component side
2. Heat with hot air at 200 °C for 30 seconds
3. Hold soldering iron to the side of the standoff and pad, and apply solder evenly around the standoff
4. Let cool and verify the standoff is centered
5. Inspect the bottom side; ideally some solder has migrated through the hole for mechanical strength

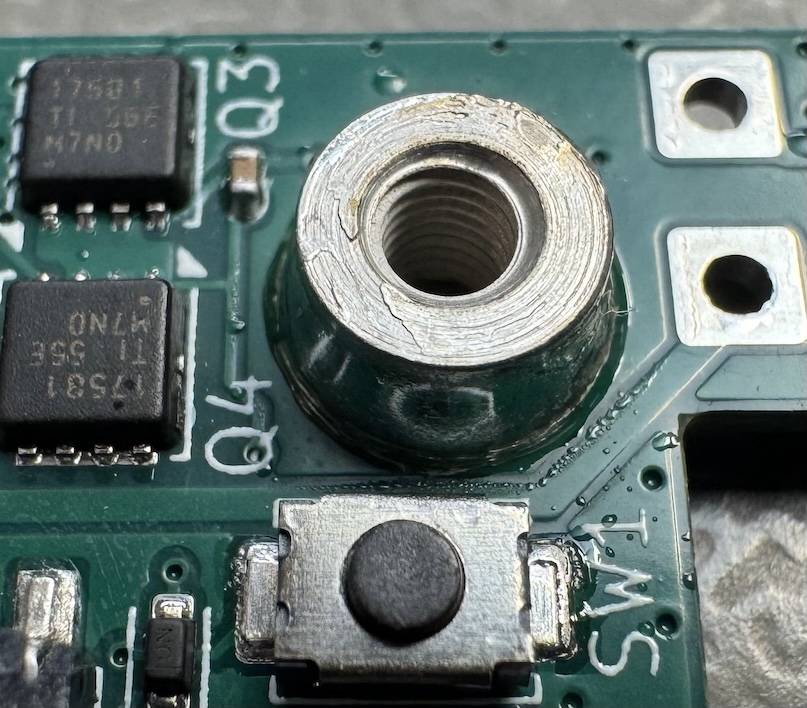
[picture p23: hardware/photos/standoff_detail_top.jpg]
Standoff detail top
  
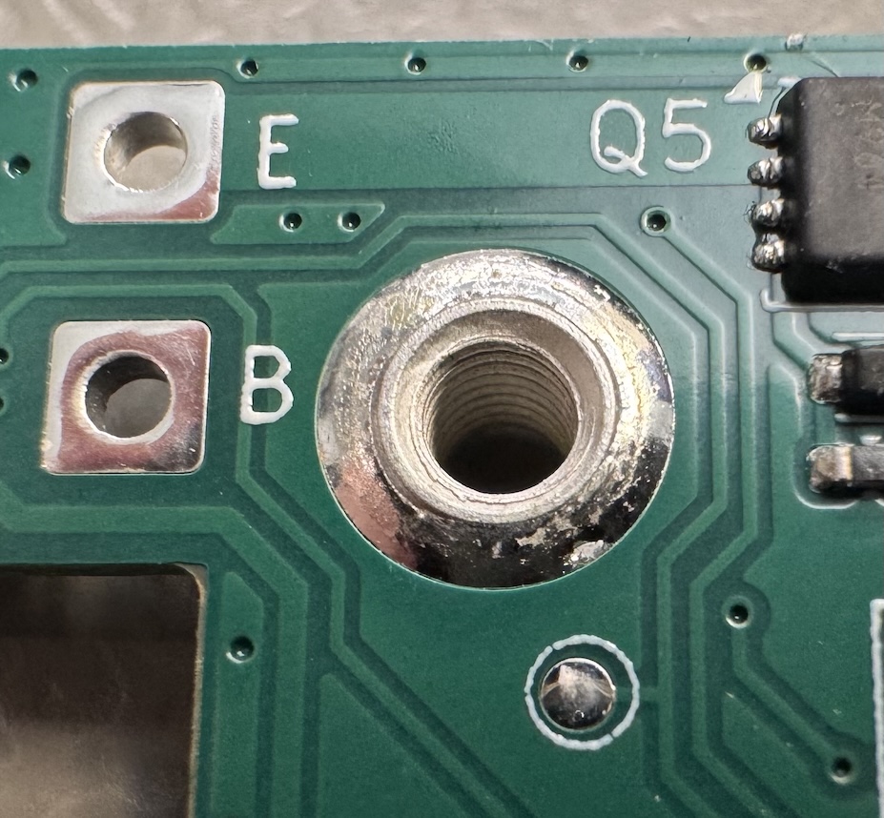
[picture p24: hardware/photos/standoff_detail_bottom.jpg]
Standoff detail bottom


#### Installing the wires

1. Cut ~50 mm pieces of white and red silicone wire
2. Strip 3 mm insulation on one end of each wire
3. Solder gold mating pins to both wires
4. Trim to total length from pin tip:
   - E (white): 31 mm
   - B (red): 43 mm
5. Strip 3 mm from open ends and solder to KXUSBC2 PCB
6. Trim excess wire close to board to prevent shorting with the side panel

PCB with wires

#### Adding insulating tape

Apply insulating tape (Kapton preferred) to the top edge of the PCB to prevent shorts due to the small clearance to the back cover.

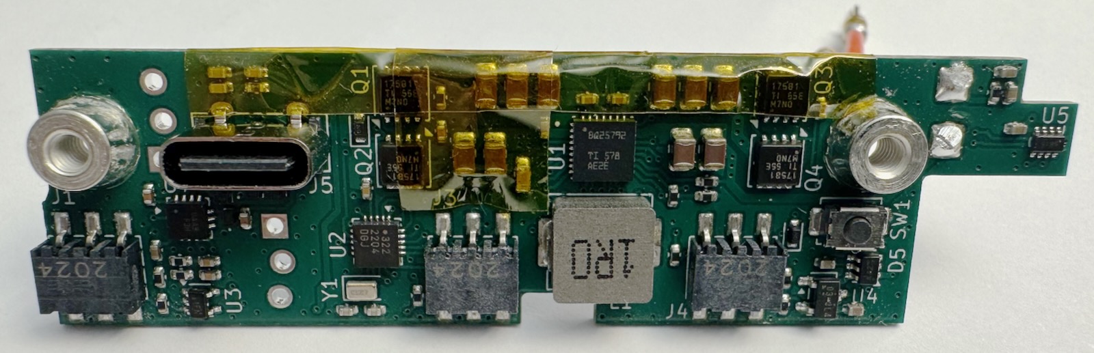
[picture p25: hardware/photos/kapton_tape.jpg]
Kapton tape applied to PCB


#### Optional: Adding the 3D printed LED diffuser

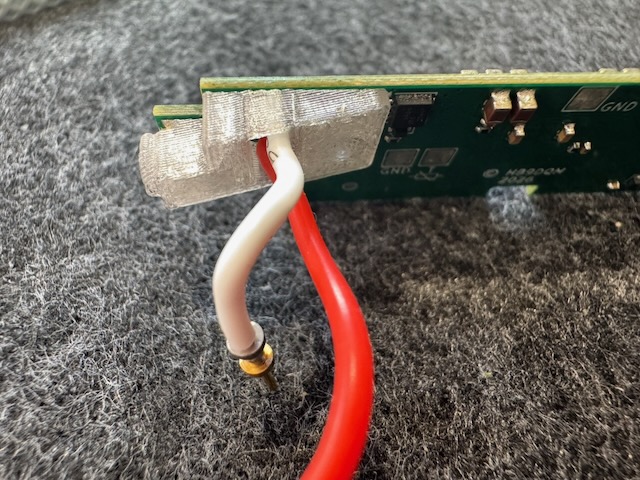
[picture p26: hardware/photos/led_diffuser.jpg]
The LED Diffuser printed and fitted to the KXUSBC2 board


This helps to diffuse the light from the LED, making it more even and reducing glare. It also helps to protect the LED from damage and the cables from strain.

**Please be very careful when fitting the part to avoid damaging the LED.**

It is recommended to place a small dab of superglue on the PCB to secure the LED diffuser in place.

### Preparing the side panel

- Remove black coating from the back side to expose bare metal (where it contacts the KX2 chassis)
- Remove coating around screw holes near USB-C and DC jack for grounding via standoffs (**important!**)
- Use a Dremel or similar power tool for efficiency (the panel in the photo below was stripped using a laser)

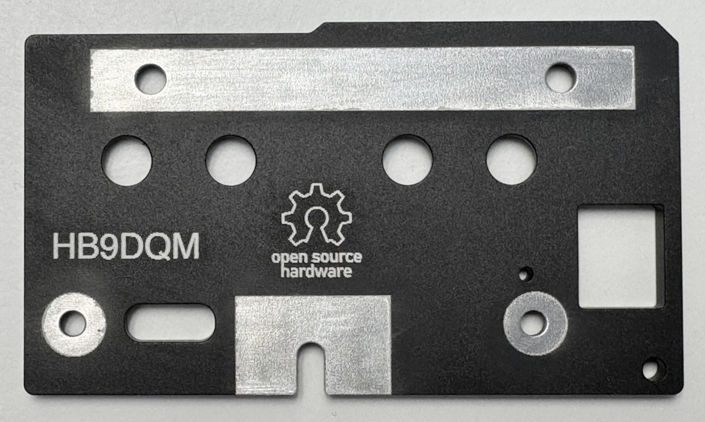
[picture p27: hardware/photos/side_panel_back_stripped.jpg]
Backside of side panel with coating stripped


---

## Part 2: Installation Guide

### Prerequisites

- Elecraft KX2 transceiver
- 3S (12.6 V) Li-Ion battery (or 4S LiFePO₄ with firmware configuration)
- KXUSBC2 board
- Replacement left side aluminum panel with USB-C opening
- Thermal pad (10 x 6 mm, 4 mm height)
- Heat shrink tube (2.5 x 15 mm)

**Optional (if not pre-installed in KX2):**
- 2 pcs. receptacle pins ([Mill-Max 8827-0-15-15-16-27-04-0](https://www.digikey.com/en/products/detail/mill-max-manufacturing-corp/8827-0-15-15-16-27-04-0/4440738)) Receptacle pin

### Preparing the KX2

➡️ **Skip this section** if your KX2 already has receptacles on the B and E pads (newer KX2, or if you've installed a KXIBC2 before).

**Solder receptacles to KX2 RF PCB:**
- Solder long, slim gold pin receptacles (Mill-Max 8827-0-15-15-16-27-04-0) to the E and B pads
- If pads are filled with solder, pre-heat with hot air and use solder wick
- The RF PCB can be removed for easier soldering on the bottom, or soldered in place

A simpler method (which makes removal more difficult, however) is not to install receptacles, but solder the pins from the KXUSBC2 directly to the B pad and the DC jack's center pin.

See the [KXIBC2 installation guide](https://ftp.elecraft.com/KX2/Manuals%20Downloads/E740370-B5,%20KXIBC2%20manual.pdf) for a detailed explanation of both methods.

Receptacles on KX2 RF PCB

### Hardware Installation

1. Remove the KX2 back cover
2. Unplug and remove the battery
3. Unscrew the 4 screws from the left side panel (note: longer screws with finer thread will hold the KXUSBC2)
4. Connect power wires:
   - Slide heat shrink tubing onto red and white wires (optional on white)
   - Plug into KX2 RF PCB receptacles (E = white, B = red)
   - Slide tubing over pins (no need to heat shrink)

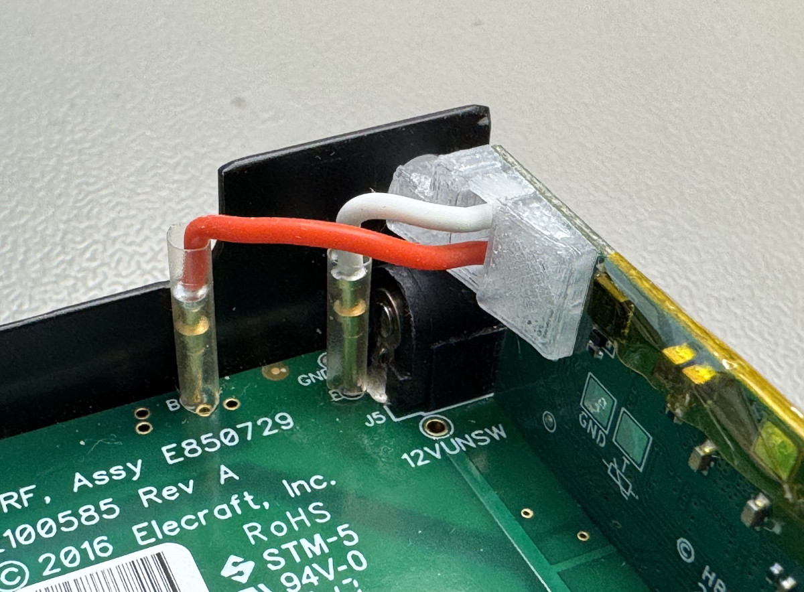
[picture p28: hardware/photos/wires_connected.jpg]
Wires connected to KX2
     
5. Plug the KXUSBC2 board into the KXIBC2/KXIO2 slot and ensure it's properly seated
   - **Bend the rear panel of the case slightly outwards to let the lens of the LED diffuser slide in**
   - Do not force the board in, or you will break off the diffuser/LED
   - One of the four connectors at the bottom edge is not used 

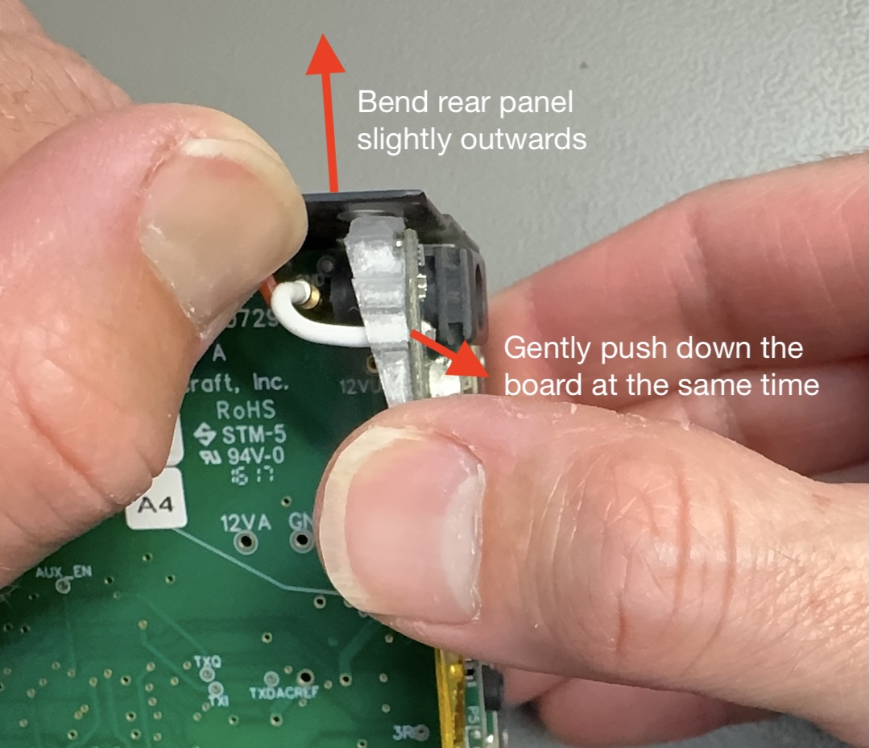
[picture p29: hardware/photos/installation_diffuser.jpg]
Installing the board by pushing the back of the case outwards
     
6. Remove protective film (if present) from both sides of the thermal pad, then place it over U1, shifted slightly to the right so as not to collide with the back cover
   
   Thermal pad placement
7. Install the replacement side panel using correct screws for each hole
8. Reinstall the battery (**important – the KXUSBC2 will not work without a battery connected**)
9. Enable KXIBC2 in KX2 menu:
    - Turn on KX2 and go to settings
    - Set KXIBC2 option to "NOR" (enables RTC and battery voltage display)
    - Update KX2 firmware if option is not present

#### Thermistor (optional)

A 10k NTC thermistor can optionally be connected between the marked pads (T and GND) on the backside of the board and attached to the battery pack with tape etc. The thermistor handling then needs to be enabled via the config button menu or the web-based programmer (see below). It will reduce or inhibit charging/discharging if the battery temperature is too high or too low.

---

## Part 3: User Guide

### Basic Operation

The KXUSBC2 adds a bidirectional USB-C port to your KX2, allowing you to:
- Charge the KX2's internal battery from any USB-C power source
- Charge external devices (phones, tablets, etc.) from the KX2's battery (OTG mode)

You can also charge from a 9-15 V supply connected to the KX2's external DC jack.

### Charging the KX2 Battery

#### Connect a power source
- Use any USB-C charger, power bank, or computer USB port
- Supports USB PD 3.0, QC, and BC1.2 protocols
- You can also connect a DC power supply (9-15 V) to the KX2's DC jack
- Maximum charging power: 30 W

#### Charging behavior
- The board automatically negotiates the best available voltage/current profile
- Delay of 3 seconds for non-PD-capable sources before charging begins
- Default charging current: 2 A (configurable, max. 3 A)
- Charging voltage: 12.6 V for 3S Li-Ion (configurable for other battery types)
- The charger uses either USB-C or the DC jack input, whichever is connected first

#### Charging while operating
- By default, charging is inhibited when the KX2 is powered on (to avoid any chance of QRM)
- This can be changed in firmware configuration if desired

### Using OTG/Source Mode (On-The-Go = Charging External Devices)

#### Starting OTG mode
- Connect a USB-C sink (phone, tablet, GPS, etc.) to the port
- The board will automatically detect and switch to source mode

#### Power output
- Maximum output: 30 W (5-15 V)
- Default current limit: 3 A (configurable)
- Minimum battery voltage: 9.0 V (configurable, prevents over-discharge)

#### Low battery protection
- If battery voltage drops below the limit, discharging stops
- LED will blink red (2 Hz)
- Recharge the battery before OTG mode will work again

### LED Status Indicators

The RGB LED provides visual feedback on the board's status:

| State | Color | Pattern |
|---|---|---|
| Disconnected | Off | - |
| Negotiating PD | Green/Yellow (*) | Blinking 5 Hz |
| Charging | Green/Yellow (*) | Pulsing (frequency indicates current) |
| Fully charged | Green | Steady |
| Temperature warning | Red | Steady |
| Fault (over-voltage/current) | Red | Blinking 5 Hz |
| Fault (low battery in OTG) | Red | Blinking 2 Hz |
| Fault (charger init) | Red | 3 blinks at 2 Hz, then pause |
| Fault (EEPROM) | Red | 4 blinks at 2 Hz, then pause |
| Rig on (charging inhibited) | Magenta | Steady |
| Discharging (OTG) | Blue/Cyan (*) | Pulsing (frequency indicates current) |

(*) Yellow/Cyan indicates temperature in "warm" or "cool" region (reduced current)

**Pulsing frequency indicates charge/discharge current:**
- < 500 mA: 8.5 s cycle
- 500-999 mA: 2.5 s cycle
- 1000-1999 mA: 1.2 s cycle
- ≥ 2000 mA: 0.8 s cycle

### Battery Voltage Monitoring

The KX2 can display the battery voltage in the menu (like with KXIBC2):
- Set the "KXIBC2" menu option to "NOR" in the KX2 configuration
- The battery voltage will appear as "BT" in the KX2 VFO B display

### Real-Time Clock (RTC)

The KXUSBC2 includes an RTC that works with the KX2's clock functions:
- Automatically temperature-compensated
- Calibrate using the KX2's "RTC ADJ" menu as usual
- Maximum correction: ±127 ppm (about 11 seconds per day)

### Config Button

The KXUSBC2 has a small push button that can be accessed using a paper clip etc. through the side panel.

#### Button Press Functions

- **Short press** (< 1 second): Attempt a PD role swap
  - Useful for charging from devices that can also act as a power source (e.g., recent iPhones)
  
- **Medium press** (1–3 seconds): Enter the config menu
  - Only works when nothing is connected to the KXUSBC2 (LED is off)
  
- **Long press** (> 3 seconds): System reset
  - Restarts the KXUSBC2

#### Config Menu Navigation

When you enter the config menu, the LED blinks yellow at 1-second intervals. The number of blinks indicates which menu item you're currently viewing.

**Menu Navigation:**
- **Short press**: Advance to the next menu item
- **Medium press**: Enter the currently selected menu item (LED will blink blue to show the current setting)
  - While viewing settings:
    - **Short press** changes the setting
    - **Medium press** exits the menu item
- **Long press**: Exit the menu and restart with new settings

#### Config Menu Items

| Menu Item | Description | Available Values (blink counts) |
|:---|:---|:---|
| 1 | Charging current limit | 500 mA (1), 1000 mA (2), 2000 mA (3), 3000 mA (4) |
| 2 | DC input current limit | 500 mA (1), 1000 mA (2), 2000 mA (3), 3000 mA (4) |
| 3 | Charge while rig is on | Disable (1), Enable (2) |
| 4 | Thermistor | Disable (1), Enable (2) |

**Example**: To enable charging while the rig is on:
1. Press the button for 1–3 seconds (LED blinks yellow, indicating menu item 1)
2. Press the button briefly two times to reach menu item 3 (LED will blink 3 times before cycling)
3. Press the button for 1–3 seconds to enter menu item 3 (LED blinks blue once, indicating that the setting is currently disabled)
4. Press the button briefly to toggle to "enable" (two blinks)
5. Press the button for 1–3 seconds to exit the menu item
6. Press the button for > 3 seconds to restart

### Configuration Options

Advanced settings can be configured via EEPROM. The web-based programmer at https://manuelkasper.github.io/kxusbc2/programmer can be used to easily change the settings without installing any software (requires a simple serial UPDI programming adapter).

- **Role**: SRC, SNK, DRP (default), TRY_SRC, TRY_SNK
- **PD mode**: Off, PD 2.0, PD 3.0 (default)
- **Charging current limit**: 50-5000 mA (default: 2000 mA)
- **Charging voltage limit**: 10000-18800 mV (default: 12600 mV for 3S Li-Ion)
- **DC input current limit**: 100-3300 mA (default: 3000 mA)
- **OTG current limit**: 120-3320 mA (default: 3000 mA)
- **Discharging voltage limit**: Minimum battery voltage for OTG (default: 9000 mV)
- **OTG voltage headroom**: 0-500 mV (default: 100 mV)
- **Allow charging while rig is on**: Boolean (default: false)
- **Enable thermistor**: Boolean (default: false)
- **User RTC offset**: -127 to +127 ppm (default: 0)

For 4S LiFePO₄ batteries, adjust the charging voltage limit to approximately 14.2 V (stay below the BMS cutoff to avoid over-voltage faults).

### Troubleshooting

**LED blinks red continuously (5 Hz)**
- Over-voltage or over-current fault detected
- Check power source specifications
- Verify battery connections

**LED blinks red continuously (2 Hz) during OTG**
- Battery voltage too low for discharging
- Recharge the battery

**Charging doesn't start**
- Check that power source supports USB PD, QC, or BC1.2
- Ensure KX2 is powered off (if charging while on is disabled)

**OTG mode doesn't work**
- Ensure battery voltage is above the discharge limit (default 9.0 V)
- Try disconnecting and reconnecting the device
- Check that the connected device can accept USB-C power input

**Battery voltage not showing in KX2 menu**
- Set "KXIBC2" option to "NOR" in KX2 configuration menu

**QRM concerns**
- QRM is minimal (typically S1 noise floor increase)
- No QRM when USB/DC is disconnected
- Charging is automatically disabled when KX2 is on (by default)
- Can be enabled in configuration if needed

### Technical Specifications

- **Charger IC**: BQ25792 buck-boost converter
- **USB-C controller**: FUSB302B
- **Microcontroller**: ATtiny3226
- **Switching frequency**: 1.5 MHz
- **Standby current**: ~60 µA
- **Supported protocols**: USB PD 3.0, QC, BC1.2
- **Battery types**: 3S Li-Ion (default), 4S LiFePO₄ (with configuration)

### Safety Notes

- Always use batteries with built-in protection and balancing circuits
- The KXUSBC2 is an unofficial modification and may void your KX2 warranty
- Use at your own risk
- Ensure proper grounding through the side panel mounting

### Support and Resources

- Project repository: https://github.com/manuelkasper/kxusbc2
- Hardware schematic: See `hardware/README.md`
- Firmware details: See `firmware/README.md`
- KXIBC2 manual (for reference): https://ftp.elecraft.com/KX2/Manuals%20Downloads/E740370-B5,%20KXIBC2%20manual.pdf

---

**Disclaimer**: This is an unofficial modification. Elecraft ® is a registered trademark of Elecraft, Inc. This project is not affiliated with or endorsed by Elecraft.

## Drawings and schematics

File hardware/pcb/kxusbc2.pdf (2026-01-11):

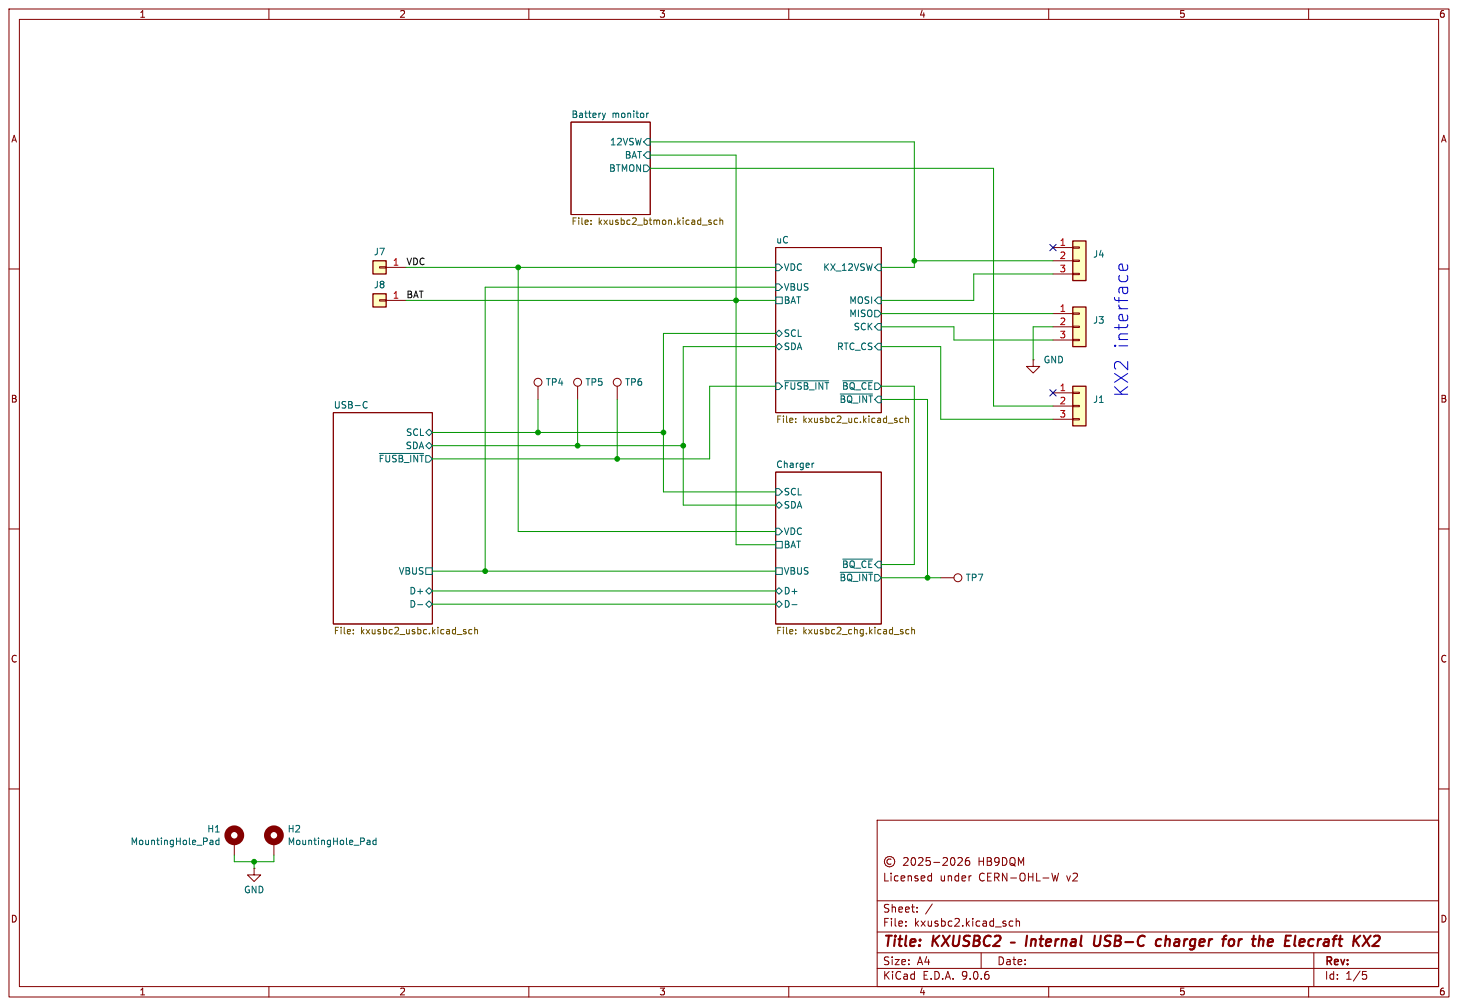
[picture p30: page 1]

Id: 1/5 Title: KXUSBC2 þÿ Internal USB-C charger for the Elecraft KX2

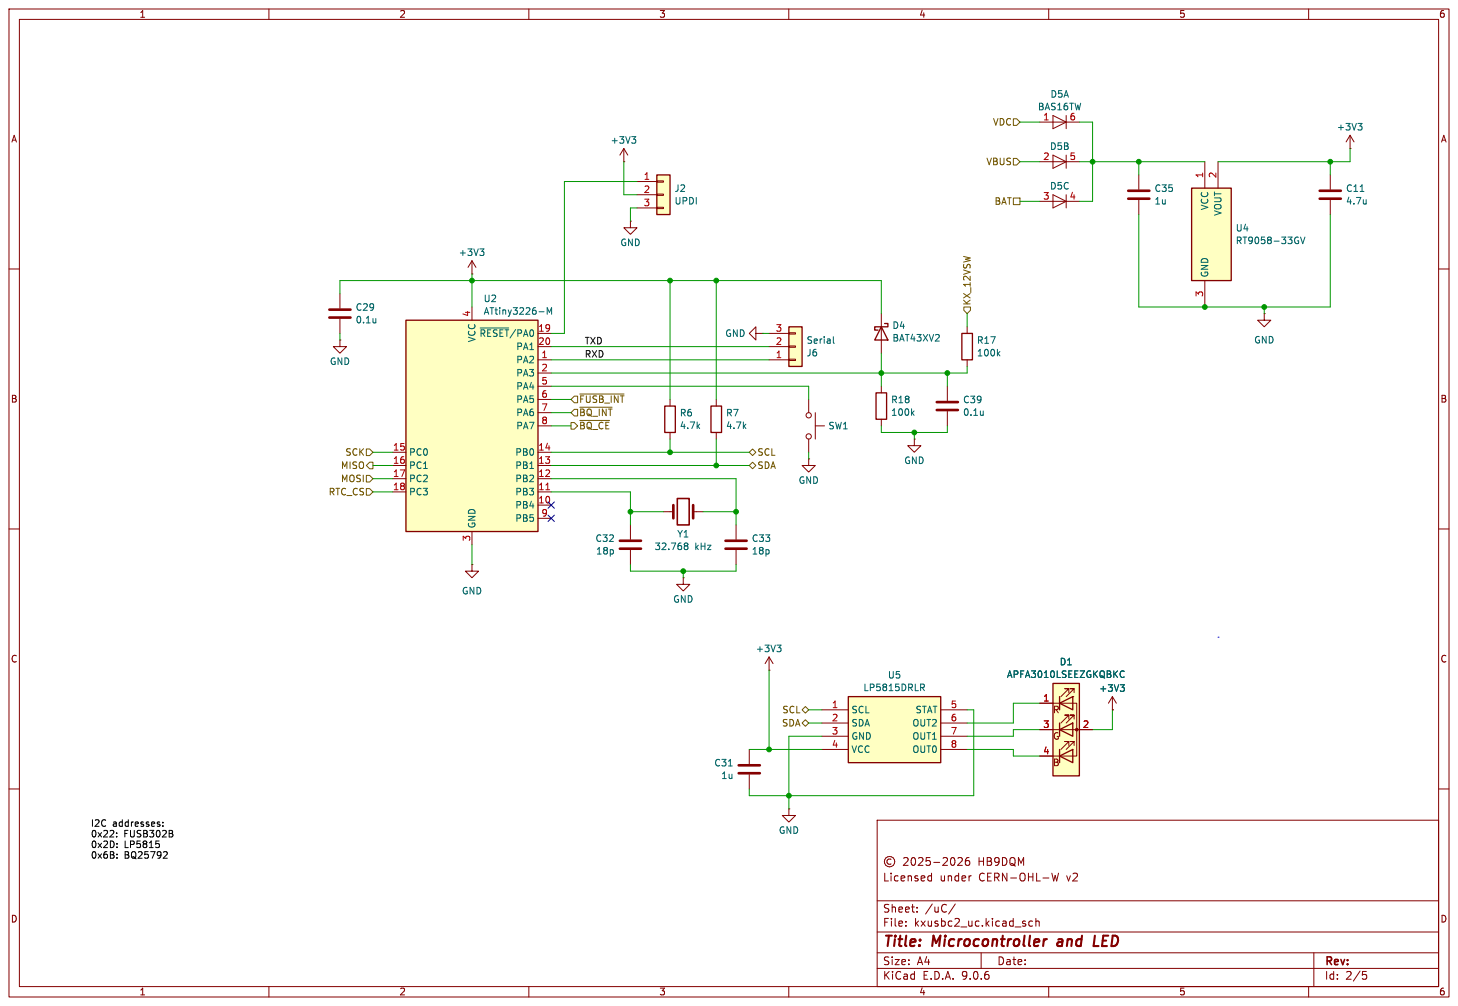
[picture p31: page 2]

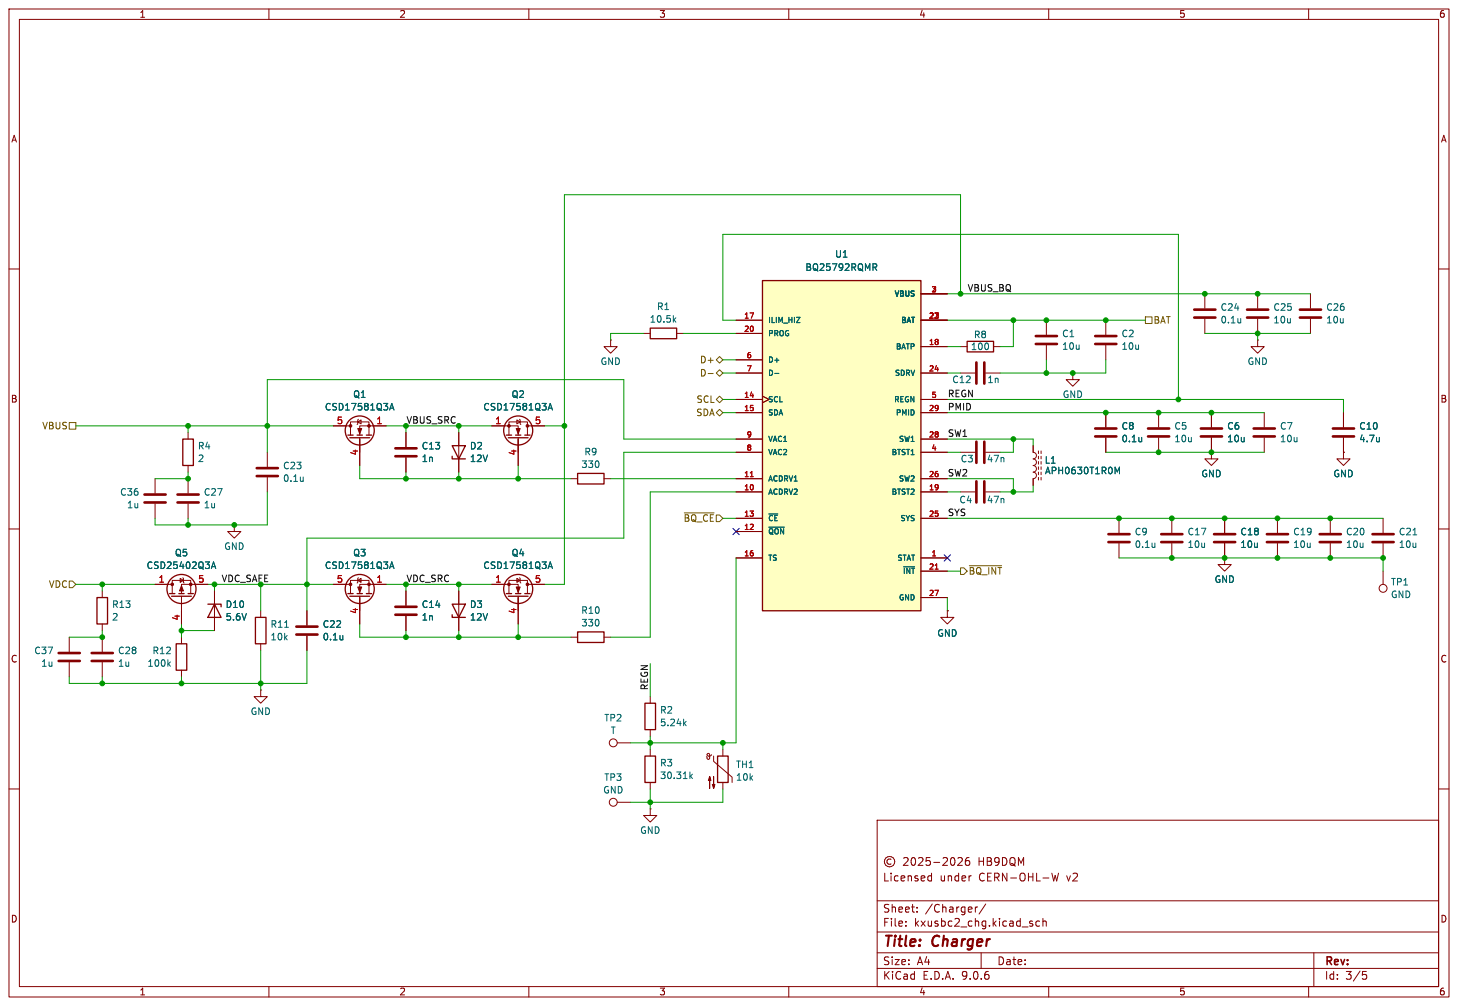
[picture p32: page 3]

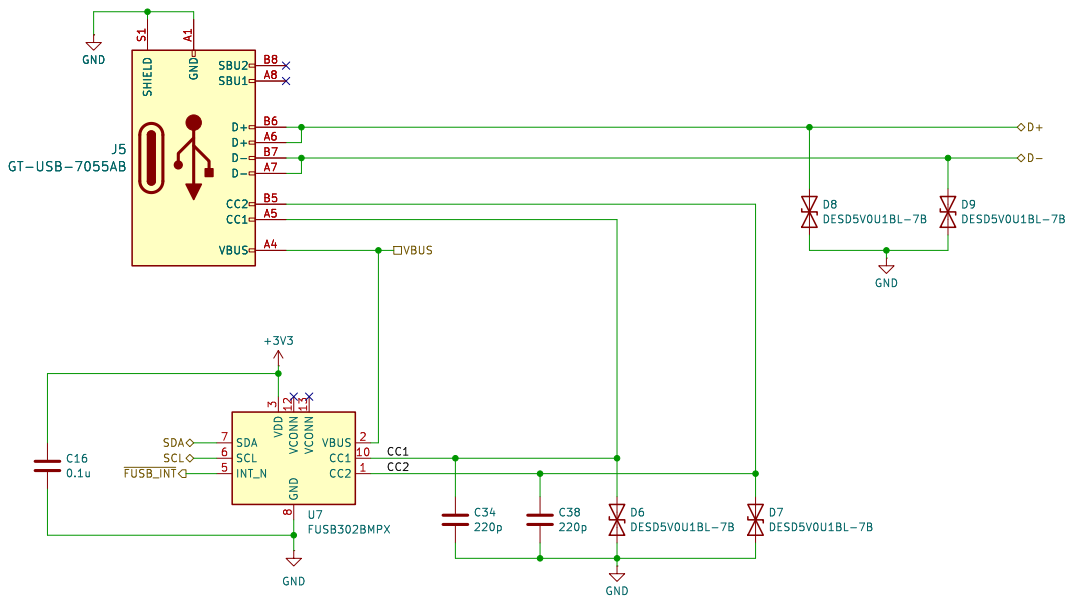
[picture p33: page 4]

8 VCONN 13 VBUS 2 CC1 10 CC2 1 U7 FUSB302BMPX D6 DESD5V0U1BL-7B D7 DESD5V0U1BL-7B GND GND

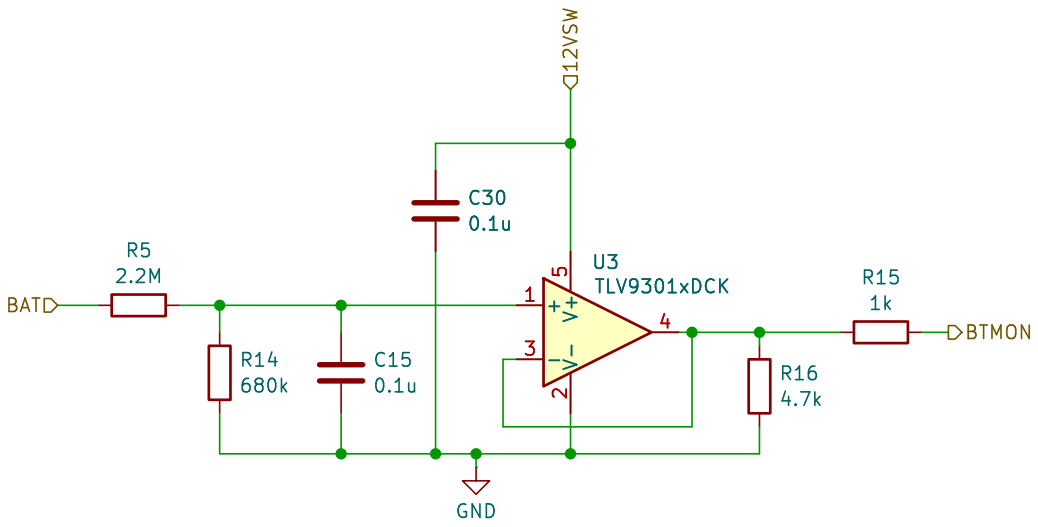
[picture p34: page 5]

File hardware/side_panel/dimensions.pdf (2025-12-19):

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

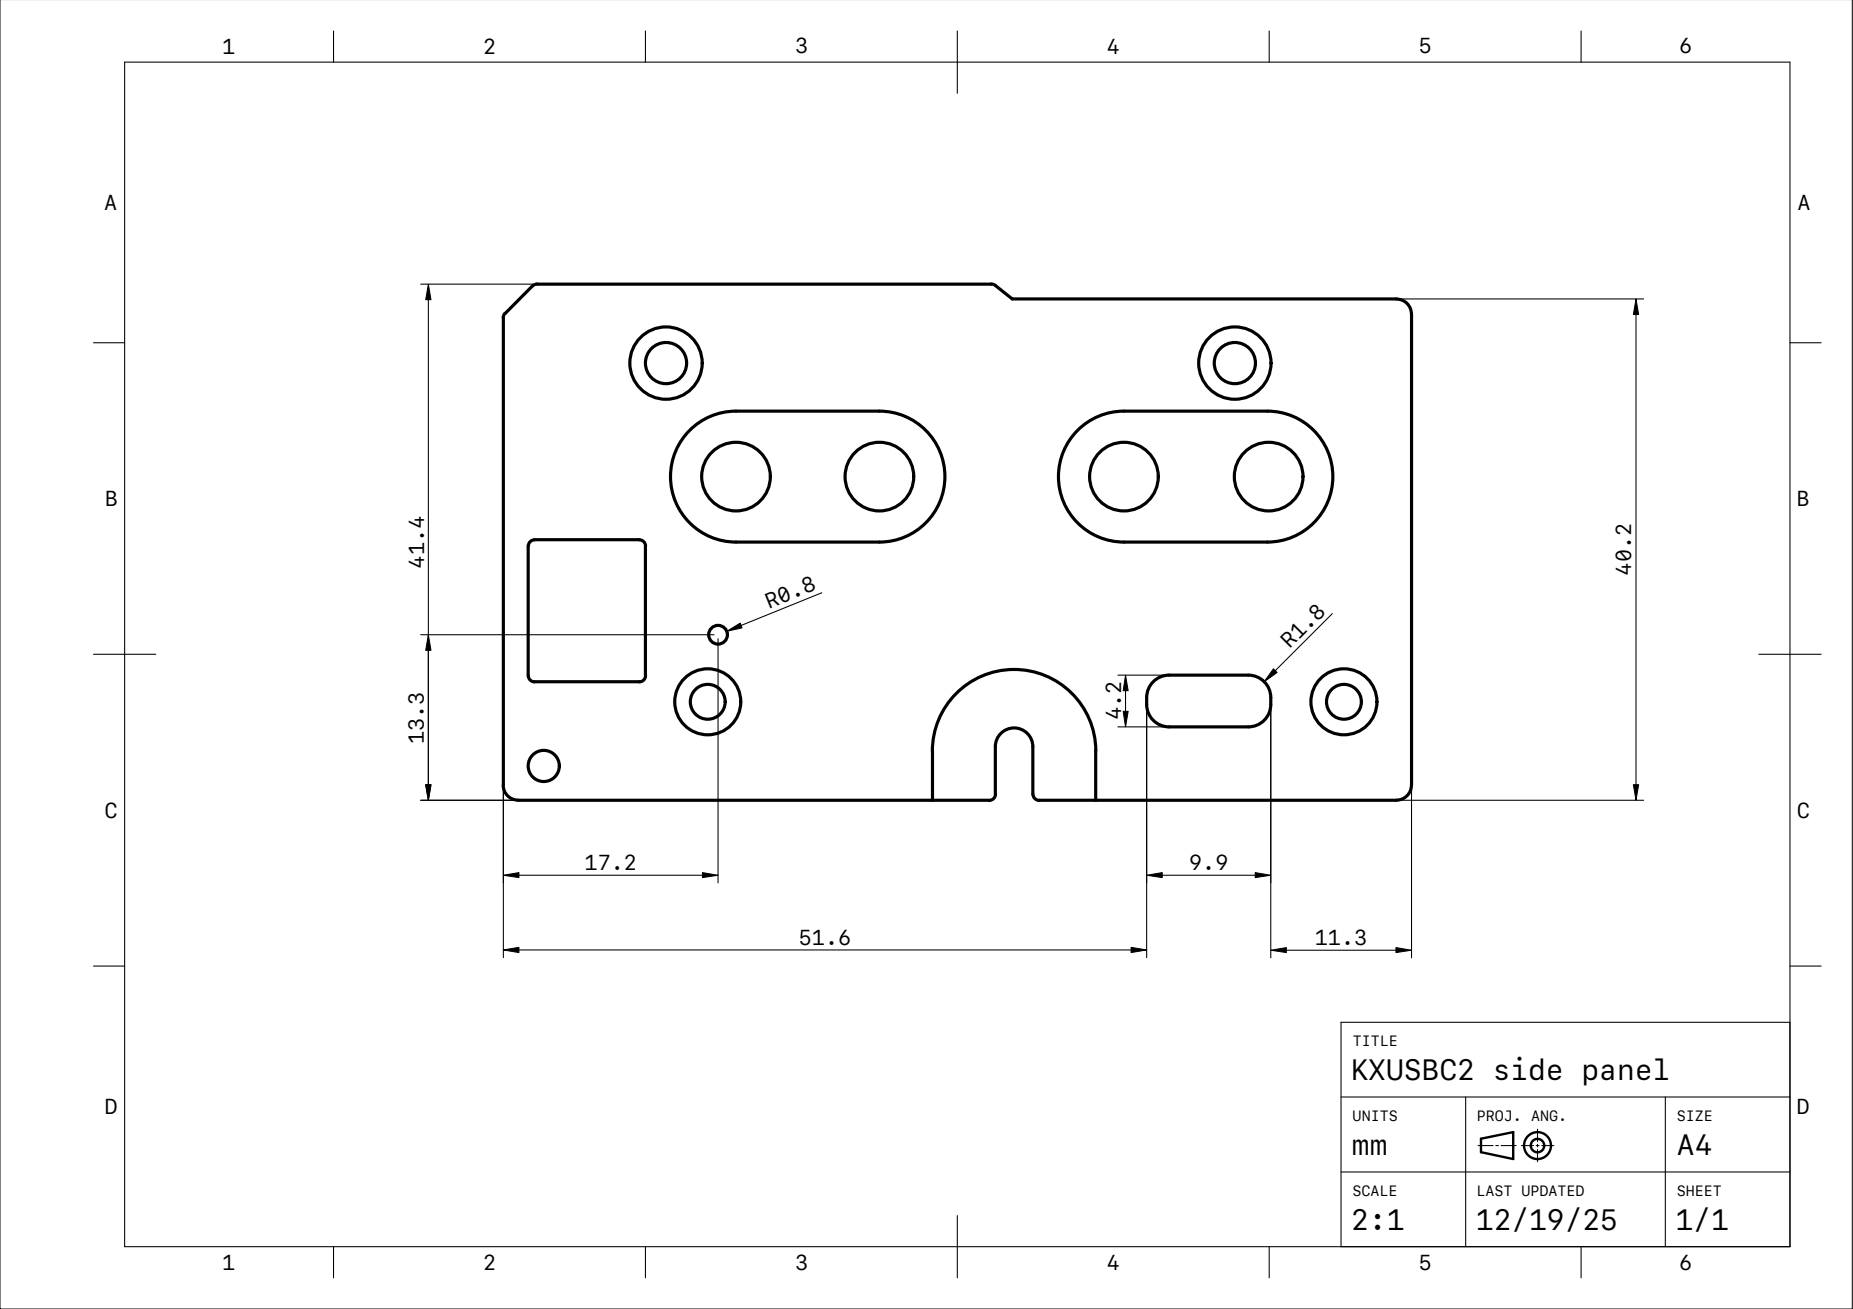
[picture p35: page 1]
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

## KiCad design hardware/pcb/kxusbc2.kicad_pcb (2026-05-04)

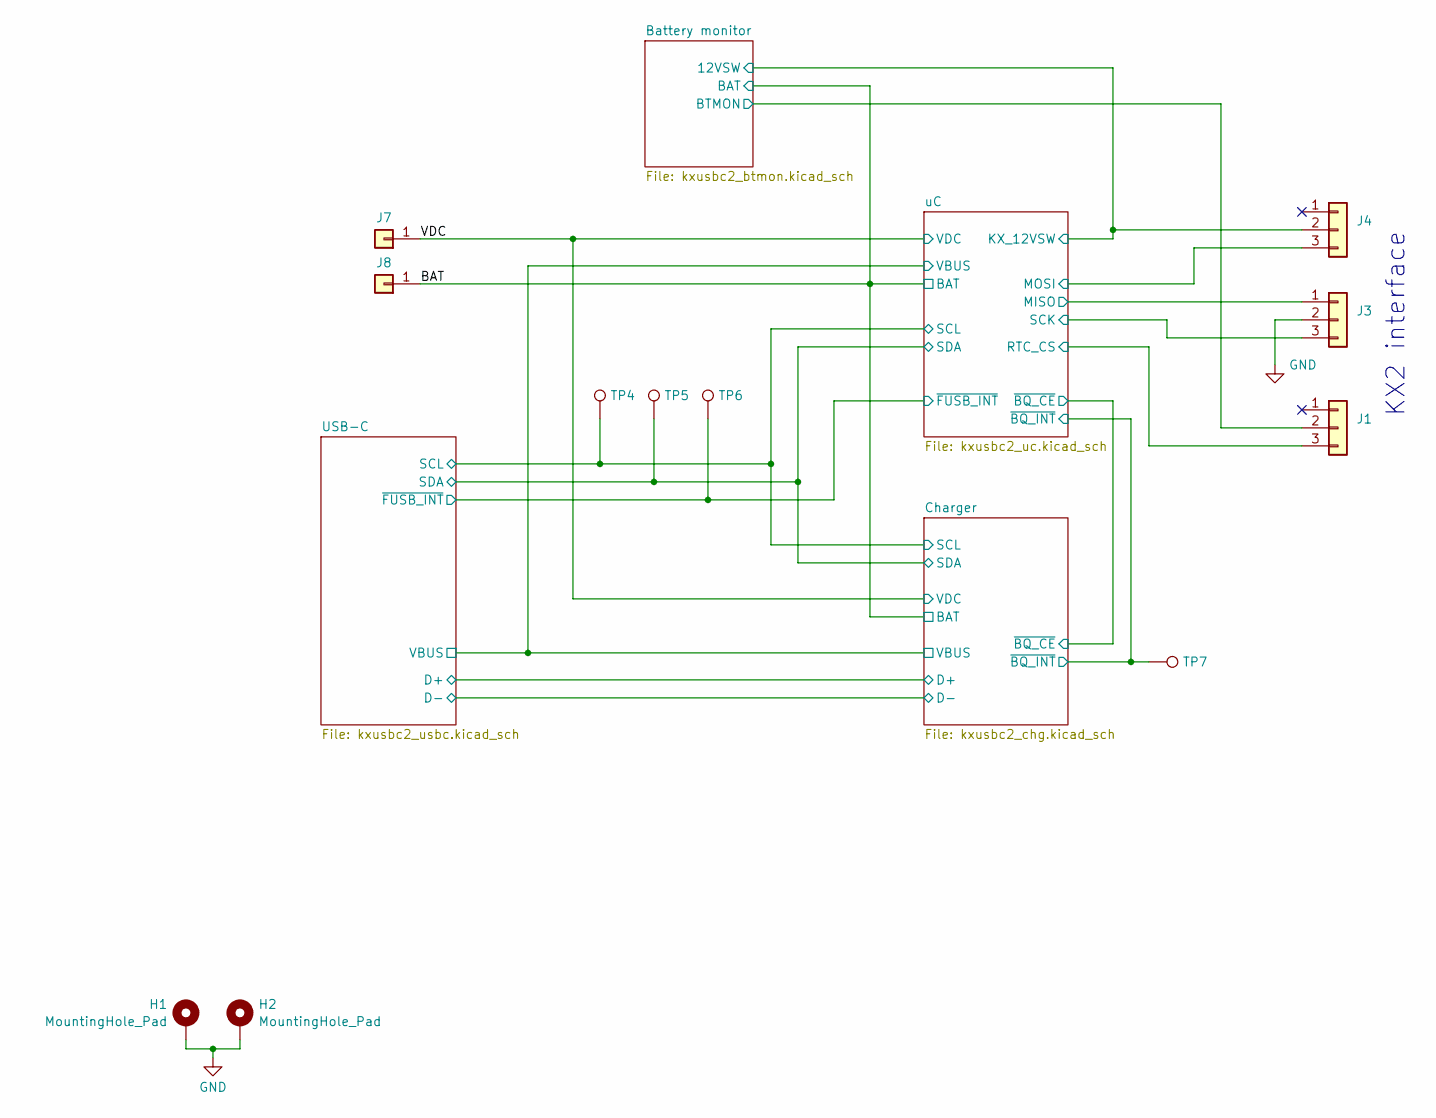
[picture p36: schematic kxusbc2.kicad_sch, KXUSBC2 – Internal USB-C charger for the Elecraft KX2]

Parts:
H1: MountingHole_Pad; Wuerth_9774030151_HS; LCSC C5373032
H2: MountingHole_Pad; Wuerth_9774030151_HS
J1, J3, J4: Conn_01x03; TE_1-2307727-3; LCSC C3322456
J7, J8: Conn_01x01; SolderWire-0.5sqmm_1x01_D0.9mm_OD2.3mm
TP4, TP5, TP6, TP7: TestPoint; TestPoint_Pad_D1.0mm

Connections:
/BAT: J8.1; also elsewhere on the board
/Battery monitor/12VSW: J4.2; also elsewhere on the board
/Battery monitor/BTMON: J1.2; also elsewhere on the board
/Charger/SCL: TP4.1; also elsewhere on the board
/Charger/SDA: TP5.1; also elsewhere on the board
/Charger/~BQ_INT: TP7.1; also elsewhere on the board
/USB-C/~FUSB_INT: TP6.1; also elsewhere on the board
/VDC: J7.1; also elsewhere on the board
/uC/MISO: J3.1; also elsewhere on the board
/uC/MOSI: J4.3; also elsewhere on the board
/uC/RTC_CS: J1.3; also elsewhere on the board
/uC/SCK: J3.3; also elsewhere on the board
GND: H1.1, H2.1, J3.2; also elsewhere on the board

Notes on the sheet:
KX2 interface

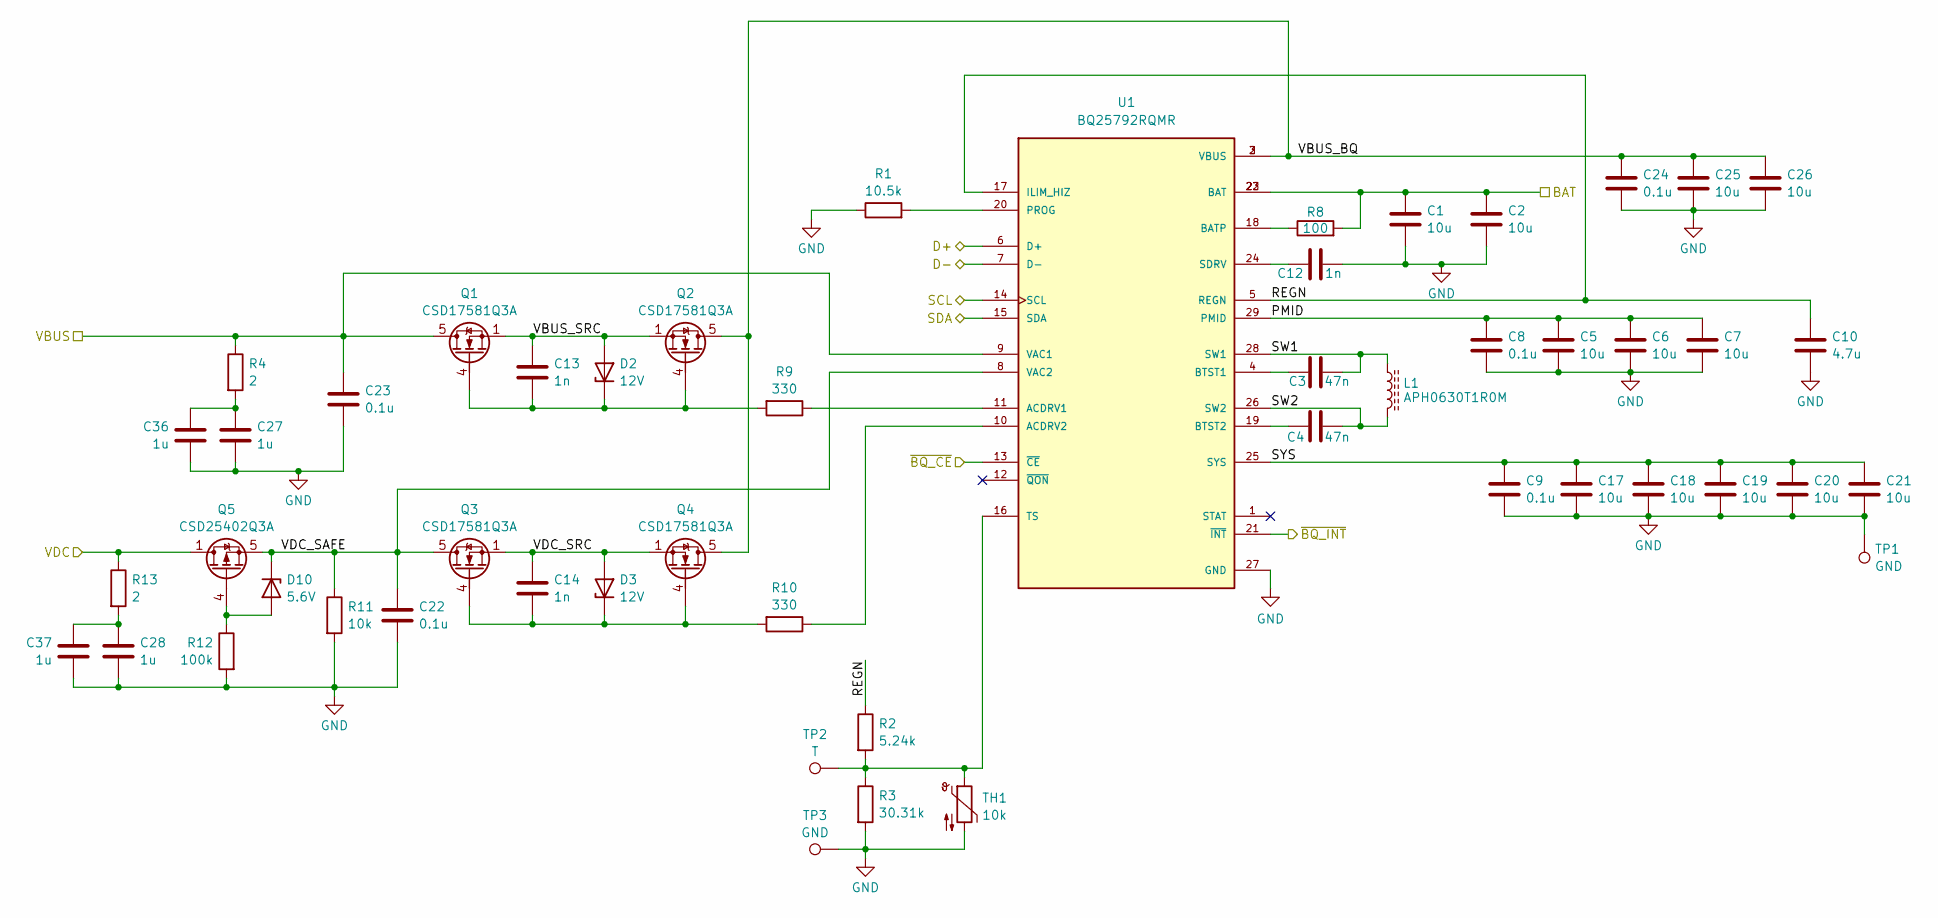
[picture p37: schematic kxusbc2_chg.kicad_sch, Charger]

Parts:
C1, C2, C5, C6, C7, C17, C18, C19, C20, C21, C25, C26: 10u; C_0805_2012Metric; LCSC C440198
C3: 47n; C_0603_1608Metric; LCSC C1622
C4: 47n; C_0603_1608Metric
C8, C9, C22, C23, C24: 0.1u; C_0402_1005Metric; LCSC C307331
C10: 4.7u; C_0603_1608Metric; LCSC C19666
C12: 1n; C_0402_1005Metric; LCSC C1588
C13, C14: 1n; C_0402_1005Metric; LCSC C1523
C27, C28, C36, C37: 1u; C_0402_1005Metric; LCSC C385032
D2, D3: 12V; D_SOD-523; LCSC C2993013
D10: 5.6V; D_SOD-523; LCSC C19077464
L1: APH0630T1R0M; L_APV_APH0630; PARTREV 20210423; LCSC C5349700
Q1, Q2, Q3, Q4: CSD17581Q3A; VSON-8_3.3x3.3mm_TI_CSD; LCSC C2861705
Q5: CSD25402Q3A; VSON-8_3.3x3.3mm_TI_CSD; LCSC C111356
R1: 10.5k; R_0402_1005Metric; LCSC C25850
R2: 5.24k; R_0402_1005Metric; LCSC C25907
R3: 30.31k; R_0402_1005Metric; LCSC C29402
R4, R13: 2; R_0402_1005Metric; LCSC C270630
R8: 100; R_0402_1005Metric; LCSC C25076
R9, R10: 330; R_0402_1005Metric; LCSC C25104
R11: 10k; R_0402_1005Metric; LCSC C25744
R12: 100k; R_0402_1005Metric
TH1: 10k
TP1, TP3: GND; TestPoint_Pad_2.5x2.5mm
TP2: T; TestPoint_Pad_2.5x2.5mm
U1: BQ25792RQMR; QFN40P400X400X100-29N; PARTREV 11/2019; LCSC C2862876

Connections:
/BAT: C1.1, C2.1, R8.2, U1.22 (BAT), U1.23 (BAT); also elsewhere on the board
/Charger/D+: U1.6 (D+); also elsewhere on the board
/Charger/D-: U1.7 (D-); also elsewhere on the board
/Charger/PMID: C5.1, C6.1, C7.1, C8.1, U1.29 (PMID)
/Charger/REGN: C10.1, R2.1, U1.5 (REGN), U1.17 (ILIM_HIZ)
/Charger/SCL: U1.14 (SCL); also elsewhere on the board
/Charger/SDA: U1.15 (SDA); also elsewhere on the board
/Charger/SW1: C3.1, L1.2, U1.28 (SW1)
/Charger/SW2: C4.2, L1.1, U1.26 (SW2)
/Charger/SYS: C9.1, C17.1, C18.1, C19.1, C20.1, C21.1, U1.25 (SYS)
/Charger/VBUS: C23.1, Q1.5 (D), R4.1, U1.9 (VAC1); also elsewhere on the board
/Charger/VBUS_BQ: C24.1, C25.1, C26.1, Q2.5 (D), Q4.5 (D), U1.2 (VBUS), U1.3 (VBUS)
/Charger/VBUS_SRC: C13.1, D2.2 (A), Q1.1 (S), Q1.2 (S), Q1.3 (S), Q2.1 (S), Q2.2 (S), Q2.3 (S)
/Charger/VDC_SAFE: C22.1, D10.1 (K), Q3.5 (D), Q5.5 (S), R11.1, U1.8 (VAC2)
/Charger/VDC_SRC: C14.1, D3.2 (A), Q3.1 (S), Q3.2 (S), Q3.3 (S), Q4.1 (S), Q4.2 (S), Q4.3 (S)
/Charger/~BQ_CE: U1.13 (~CE); also elsewhere on the board
/Charger/~BQ_INT: U1.21 (~INT); also elsewhere on the board
/VDC: Q5.1 (D), Q5.2 (D), Q5.3 (D), R13.1; also elsewhere on the board
GND: C1.2, C2.2, C5.2, C6.2, C7.2, C8.2, C9.2, C10.2, C12.1, C17.2, C18.2, C19.2, C20.2, C21.2, C22.2, C23.2, C24.2, C25.2, C26.2, C27.2, C28.2, C36.2, C37.2, R1.1, R3.2, R11.2, R12.2, TH1.2, TP1.1, TP3.1, U1.27 (GND); also elsewhere on the board
unnamed: C27.1, C36.1, R4.2
unnamed: C28.1, C37.1, R13.2
unnamed: C13.2, D2.1 (K), Q1.4 (G), Q2.4 (G), R9.2
unnamed: C14.2, D3.1 (K), Q3.4 (G), Q4.4 (G), R10.2
unnamed: D10.2 (A), Q5.4 (G), R12.1
unnamed: R9.1, U1.11 (ACDRV1)
unnamed: R10.1, U1.10 (ACDRV2)
unnamed: R8.1, U1.18 (BATP)
unnamed: C3.2, U1.4 (BTST1)
unnamed: C4.1, U1.19 (BTST2)
unnamed: R1.2, U1.20 (PROG)
unnamed: C12.2, U1.24 (SDRV)
unnamed: R2.2, R3.1, TH1.1, TP2.1, U1.16 (TS)

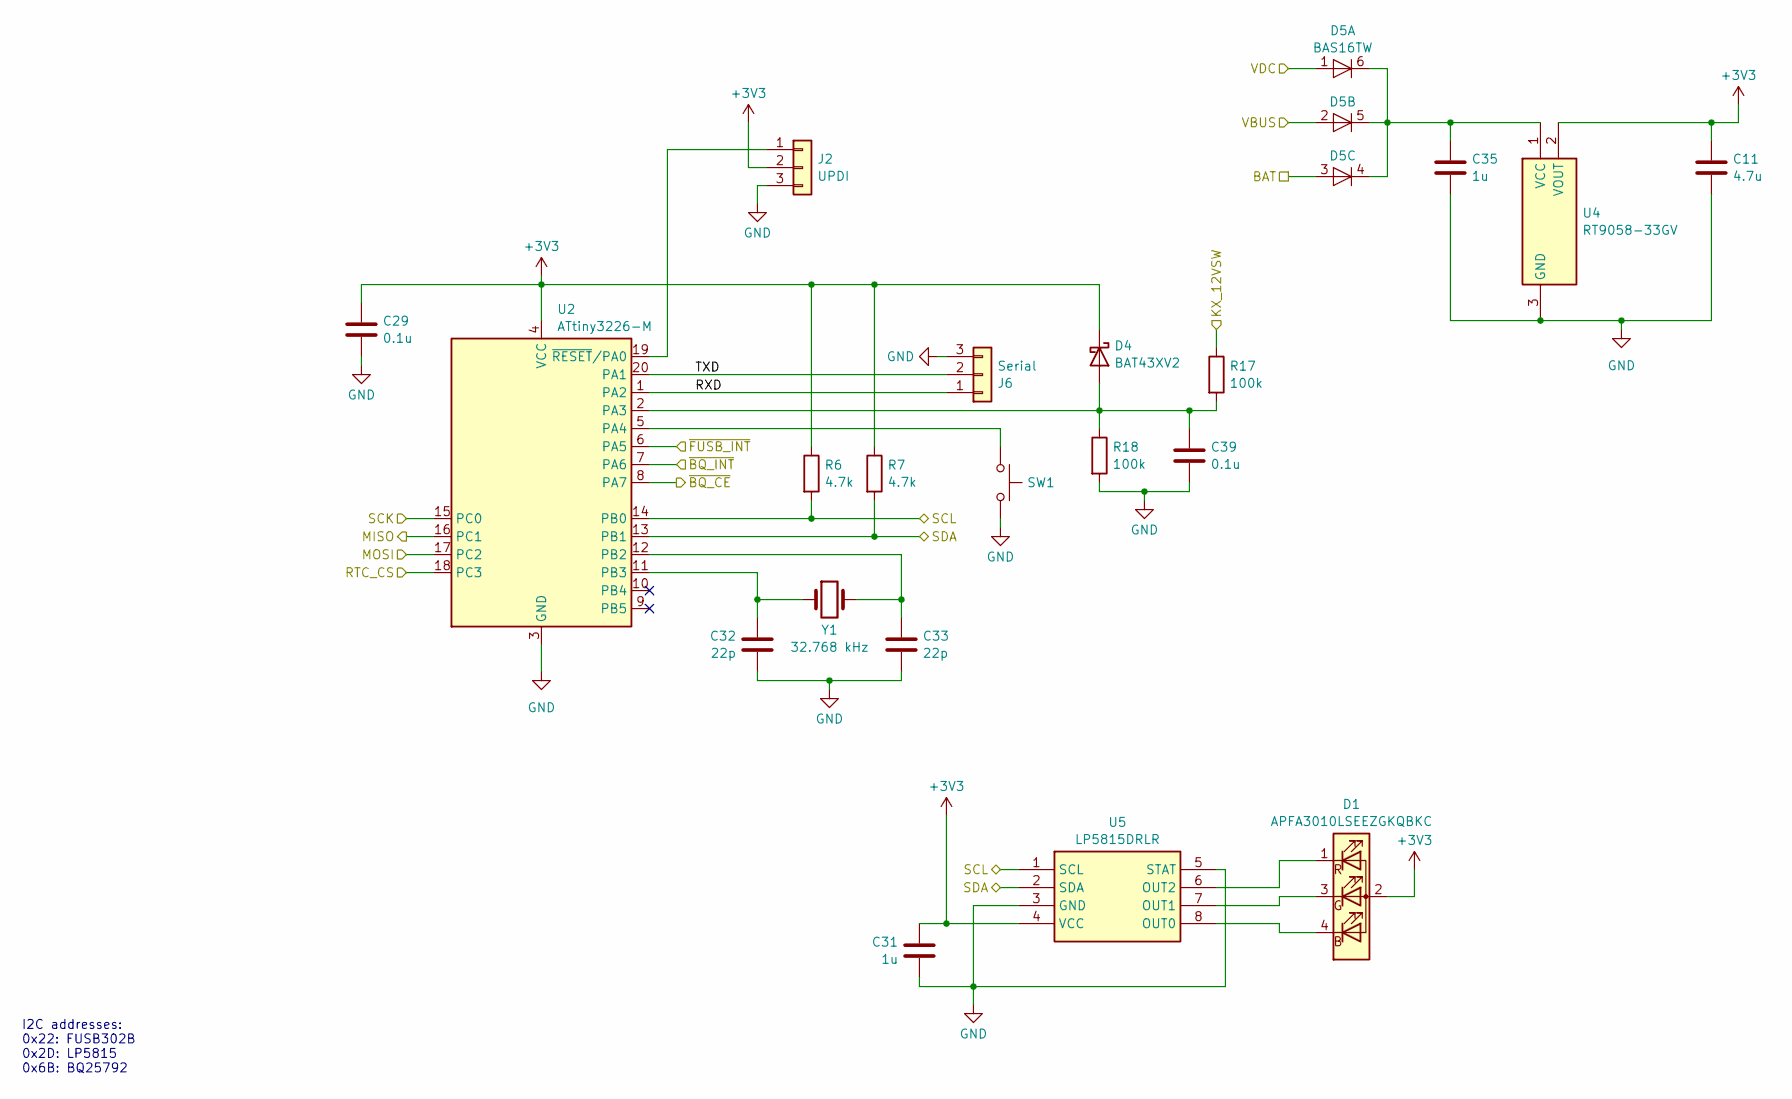
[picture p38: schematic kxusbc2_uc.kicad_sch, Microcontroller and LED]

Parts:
C11: 4.7u; C_0402_1005Metric; LCSC C23733
C29, C39: 0.1u; C_0402_1005Metric; LCSC C307331
C31, C35: 1u; C_0402_1005Metric; LCSC C52923
C32, C33: 22p; C_0402_1005Metric; LCSC C1555
D1: APFA3010LSEEZGKQBKC; LED_Kingbright_APFA3010_3x1.5mm_Horizontal; LCSC C5393554
D4: BAT43XV2; D_SOD-523; LCSC C463439
D5: BAS16TW; SOT-363_SC-70-6; LCSC C155382
J2: UPDI; PinHeader_1x03_P2.54mm_Vertical
J6: Serial; PinHeader_1x03_P2.54mm_Vertical
R6, R7: 4.7k; R_0402_1005Metric; LCSC C25900
R17, R18: 100k; R_0402_1005Metric; LCSC C25741
SW1: SW_Push; SW_SPST_TS-1088-xR020; LCSC C720477
U2: ATtiny3226-M; VQFN-20-1EP_3x3mm_P0.4mm_EP1.7x1.7mm; LCSC C3216895
U4: RT9058-33GV; SOT-23-3; Manufacturer_Part_Number RT9058-33GV; Mouser Part Number 835-RT9058-33GV
U5: LP5815DRLR; SOTFL50P160X60-8N; Manufacturer_Part_Number LP5815DRLR; LCSC C47262831
Y1: 32.768 kHz; Crystal_SMD_2012-2Pin_2.0x1.2mm; LCSC C276423

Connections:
+3V3: C11.1, C29.1, C31.1, D1.2 (A), D4.1 (K), J2.2, R6.1, R7.1, U2.4 (VCC), U4.2 (VOUT), U5.4 (VCC); also elsewhere on the board
/BAT: D5.3 (A); also elsewhere on the board
/Battery monitor/12VSW: R17.1; also elsewhere on the board
/Charger/SCL: R6.2, U2.14 (PB0), U5.1 (SCL); also elsewhere on the board
/Charger/SDA: R7.2, U2.13 (PB1), U5.2 (SDA); also elsewhere on the board
/Charger/VBUS: D5.2 (A); also elsewhere on the board
/Charger/~BQ_CE: U2.8 (PA7); also elsewhere on the board
/Charger/~BQ_INT: U2.7 (PA6); also elsewhere on the board
/USB-C/~FUSB_INT: U2.6 (PA5); also elsewhere on the board
/VDC: D5.1 (A); also elsewhere on the board
/uC/MISO: U2.16 (PC1); also elsewhere on the board
/uC/MOSI: U2.17 (PC2); also elsewhere on the board
/uC/RTC_CS: U2.18 (PC3); also elsewhere on the board
/uC/RXD: J6.1, U2.1 (PA2)
/uC/SCK: U2.15 (PC0); also elsewhere on the board
/uC/TXD: J6.2, U2.20 (PA1)
GND: C11.2, C29.2, C31.2, C32.1, C33.1, C35.2, C39.2, J2.3, J6.3, R18.2, SW1.2, U2.3 (GND), U2.21 (GND), U4.3 (GND), U5.3 (GND), U5.5 (STAT); also elsewhere on the board
unnamed: D1.4 (B), U5.8 (OUT0)
unnamed: D1.3 (G), U5.7 (OUT1)
unnamed: D1.1 (R), U5.6 (OUT2)
unnamed: C39.1, D4.2 (A), R17.2, R18.1, U2.2 (PA3)
unnamed: C35.1, D5.4 (K), D5.5 (K), D5.6 (K), U4.1 (VCC)
unnamed: J2.1, U2.19 (~RESET/PA0)
unnamed: SW1.1, U2.5 (PA4)
unnamed: C33.2, U2.12 (PB2), Y1.2
unnamed: C32.2, U2.11 (PB3), Y1.1

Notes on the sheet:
I2C addresses: 0x22: FUSB302B 0x2D: LP5815 0x6B: BQ25792

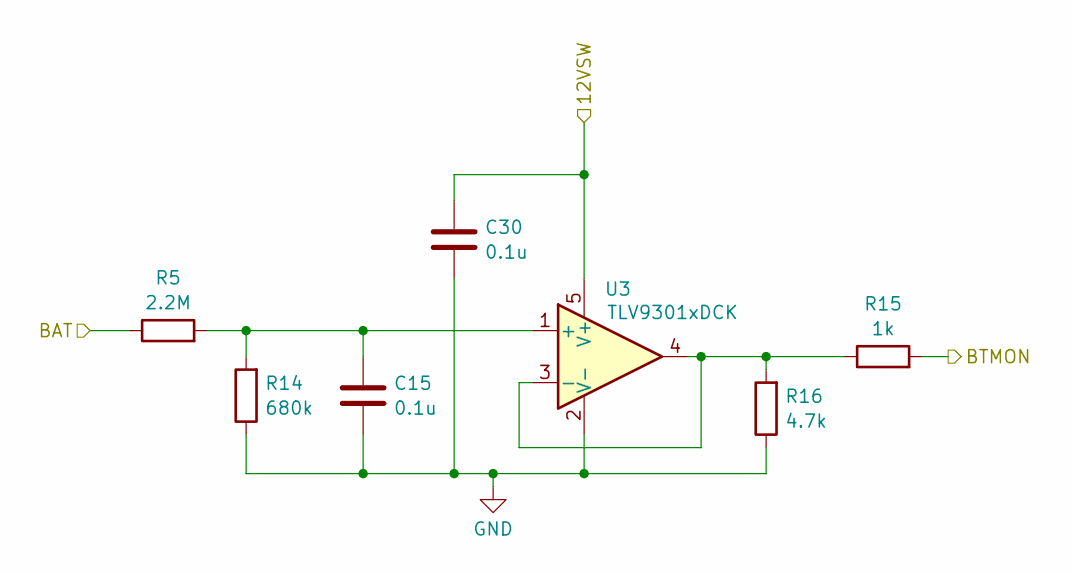
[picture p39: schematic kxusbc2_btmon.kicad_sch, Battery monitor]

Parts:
C15, C30: 0.1u; C_0402_1005Metric; LCSC C307331
R5: 2.2M; R_0402_1005Metric; LCSC C138015
R14: 680k; R_0402_1005Metric; LCSC C4131
R15: 1k; R_0402_1005Metric; LCSC C11702
R16: 4.7k; R_0402_1005Metric; LCSC C25900
U3: TLV9301xDCK; SOT-353_SC-70-5; LCSC C4366617

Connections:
/BAT: R5.1; also elsewhere on the board
/Battery monitor/12VSW: C30.1, U3.5 (V+); also elsewhere on the board
/Battery monitor/BTMON: R15.2; also elsewhere on the board
GND: C15.2, C30.2, R14.1, R16.1, U3.2 (V-); also elsewhere on the board
unnamed: C15.1, R5.2, R14.2, U3.1 (+)
unnamed: R15.1, R16.2, U3.3 (-), U3.4

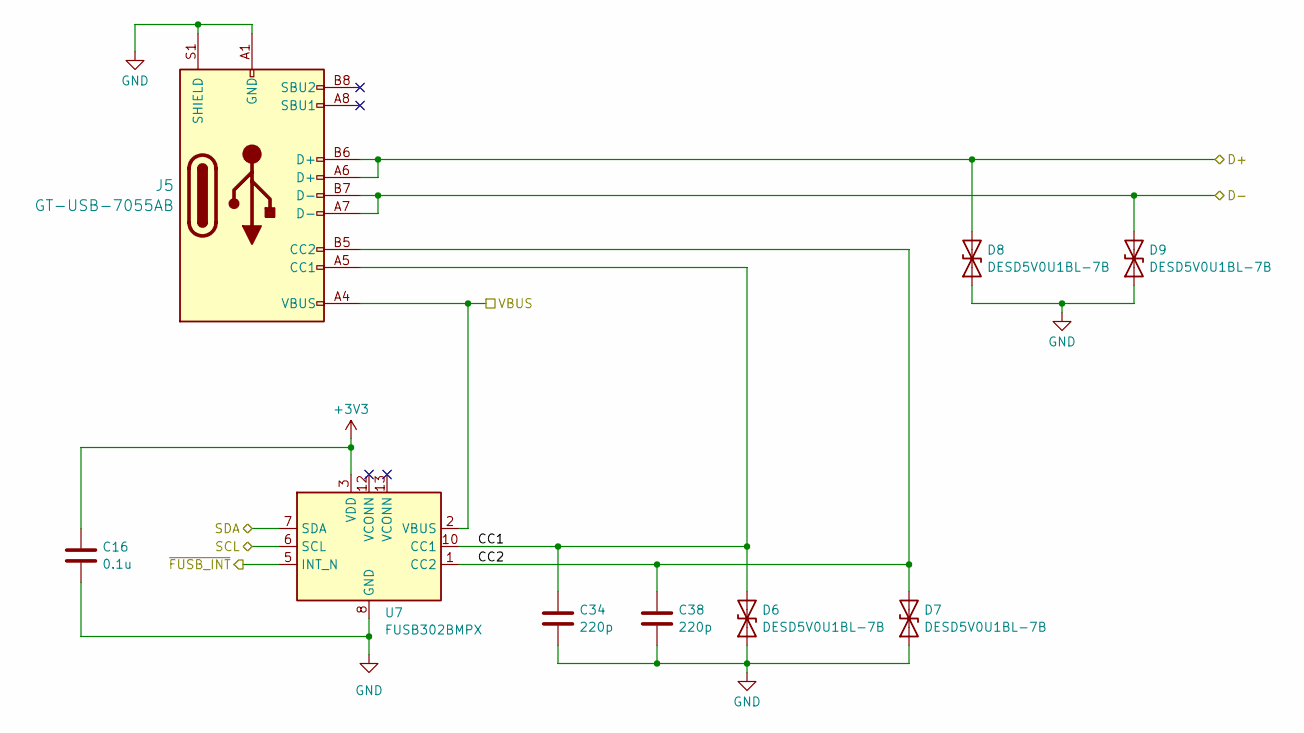
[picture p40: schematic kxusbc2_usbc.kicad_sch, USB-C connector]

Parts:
C16: 0.1u; C_0402_1005Metric; LCSC C307331
C34, C38: 220p; C_0402_1005Metric; LCSC C1530
D6, D7, D8, D9: DESD5V0U1BL-7B; DESD5V0U1BL7B; LCSC C1869323
J5: GT-USB-7055AB; CONN_GT-USB-7055A_GSW; LCSC C22383826
U7: FUSB302BMPX; WQFN-14-1EP_2.5x2.5mm_P0.5mm_EP1.45x1.45mm; LCSC C132291

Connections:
+3V3: C16.2, U7.3 (VDD), U7.4 (VDD); also elsewhere on the board
/Charger/D+: D8.2 (A2), J5.A6 (D+), J5.B6 (D+); also elsewhere on the board
/Charger/D-: D9.2 (A2), J5.A7 (D-), J5.B7 (D-); also elsewhere on the board
/Charger/SCL: U7.6 (SCL); also elsewhere on the board
/Charger/SDA: U7.7 (SDA); also elsewhere on the board
/Charger/VBUS: J5.A4 (VBUS), J5.A9 (VBUS), J5.B4 (VBUS), J5.B9 (VBUS), U7.2 (VBUS); also elsewhere on the board
/USB-C/CC1: C34.1, D6.2 (A2), J5.A5 (CC1), U7.10 (CC1), U7.11 (CC1)
/USB-C/CC2: C38.1, D7.2 (A2), J5.B5 (CC2), U7.1 (CC2), U7.14 (CC2)
/USB-C/~FUSB_INT: U7.5 (INT_N); also elsewhere on the board
GND: C16.1, C34.2, C38.2, D6.1 (A1), D7.1 (A1), D8.1 (A1), D9.1 (A1), J5.A1 (GND), J5.A12 (GND), J5.B1 (GND), J5.B12 (GND), J5.S1 (SHIELD), U7.8 (GND), U7.9 (GND), U7.15 (GND); also elsewhere on the board

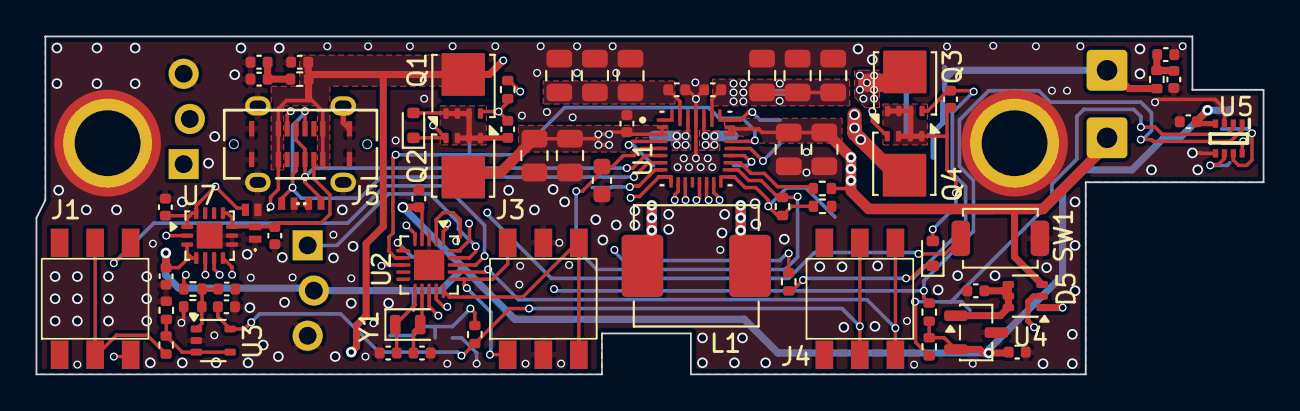
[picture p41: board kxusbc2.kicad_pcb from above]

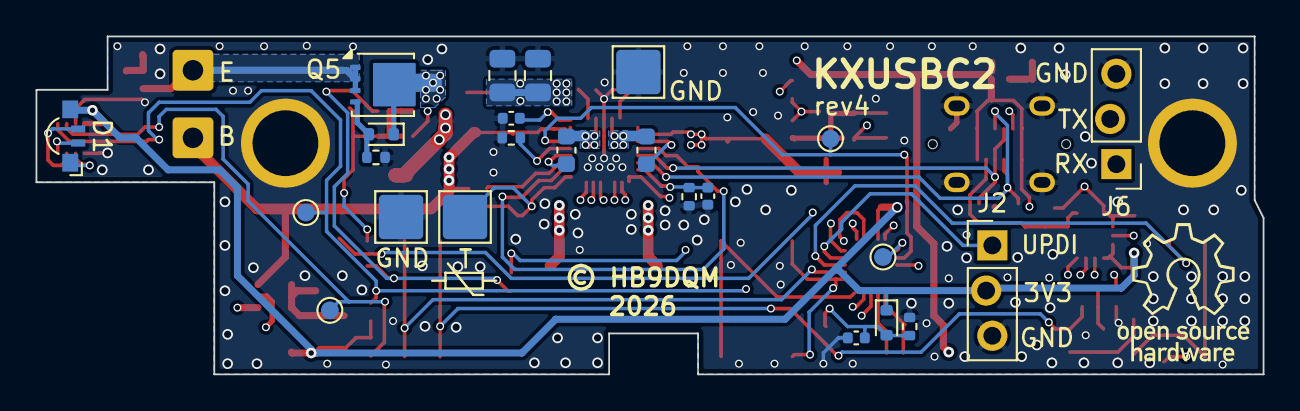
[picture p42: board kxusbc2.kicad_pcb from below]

Board: 4 copper layers, 69.0 x 19.0 mm, 98 parts (26 on the bottom side), 55 nets.

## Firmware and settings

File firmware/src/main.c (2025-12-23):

#include <avr/io.h>
#include <stdint.h>
#include <stdbool.h>
#include <util/delay.h>
#include <stdio.h>
#include <avr/interrupt.h>
#include <avr/sleep.h>

#include "debug.h"
#include "clock.h"
#include "util.h"
#include "sysconfig.h"
#include "rtc.h"
#include "led.h"
#include "bq.h"
#include "button.h"
#include "twi.h"
#include "fsc_pd_ctl.h"
#include "charger_sm.h"
#include "insomnia.h"
#include "kx2.h"
#include "watchdog.h"

#ifdef DEBUG
#define DEBUG_STATUS
#endif

#ifdef DEBUG_STATUS
static void bq_print_status(void);
#endif

#ifdef DEBUG
ISR(BADISR_vect) {
    debug_printf("Bad interrupt\n");
}
#endif

int main(void) {
    clock_init();
    watchdog_init();
    debug_init();
    twi_init();
    led_wakeup();
    led_init();
    if (!sysconfig_valid()) {
        debug_printf("Invalid EEPROM configuration\n");
        led_set_blinking(true, false, false, 255, 5, 5, 4, 11);  // Red blinking, 4 x at 2 Hz with 1 second pause
        while (1);
    }
    kx2_init();
    rtc_init();
    button_init();

    // Enable global interrupts (also used for serial debug output)
    sei();
    
    debug_printf("Startup, reset flags %x\n", RSTCTRL.RSTFR);
    RSTCTRL.RSTFR = 0xFF; // Clear reset flags
    
    if (!bq_init(sysconfig->chargingVoltageLimit, sysconfig->chargingCurrentLimit)) {
        debug_printf("BQ init failed\n");
        led_set_blinking(true, false, false, 255, 5, 5, 3, 11);  // Red blinking, 3 x at 2 Hz with 1 second pause
        while (1);
    }
    bq_set_thermistor(sysconfig->enableThermistor);

    fsc_pd_init();
    charger_sm_init();
    button_set_short_press_handler(fsc_pd_swap_roles);

    // Power up blink
    for (uint8_t i = 0; i < 3; i++) {
        led_set_color(true, true, true, 255);
        _delay_ms(200);
        led_off();
        _delay_ms(200);
    }
    led_shutdown();

    while (1) {
#ifdef DEBUG_STATUS
        static uint16_t last_bq_status = 0;
        // Re-enable in case state machine disabled it
        bq_enable_adc();
#endif

        if (button_handle_config_menu()) {
            // In config menu - skip normal processing
            watchdog_tickle();
            continue;
        }

        // Run PD state machine - returns a timeout in ticks until next required wakeup,
        // or 0 if no wakeup is needed and we can sleep until the next interrupt
        uint16_t next_timeout = fsc_pd_run();

        // Process BQ interrupts and notify state machine
        if (bq_process_interrupts()) {
            charger_sm_on_bq_interrupt();
        }

        // Run charger state machine - returns a timeout in ticks until the next required wakeup,
        // or 0 if no wakeup is needed and we can sleep until the next interrupt
        uint16_t sm_timeout = charger_sm_run();
        if (sm_timeout > 0 && (sm_timeout < next_timeout || next_timeout == 0)) {
            next_timeout = sm_timeout;
        }

        // Enter low-power mode until next RTC alarm or other interrupt
        // Don't enter sleep if we need to wake up soon (otherwise we may miss the alarm)
        if (next_timeout == 0 || next_timeout >= 100) {
            if (next_timeout != 0) {
                rtc_set_alarm(next_timeout);
            }

            // Only enter sleep mode if no insomnia mask bits are set;
            // use recommended procedure from avr/sleep.h to avoid race conditions
            set_sleep_mode(SLEEP_MODE_STANDBY);
            cli();
            if (insomnia_mask == 0) {
                sleep_enable();
                sei();
                sleep_cpu();
                sleep_disable();
            }
            sei();
        }

#ifdef DEBUG_STATUS
        uint16_t now = rtc_get_ticks();
        if ((now - last_bq_status) >= 1000) {
            bq_print_status();

            last_bq_status = now;
        }
#endif

        // Tickle the watchdog. Note that we get at least one interrupt per second due to the RTC PIT.
        // If the latter is disabled, one must make sure to set the RTC alarm at less than the watchdog timeout interval.
        watchdog_tickle();
    }

    return 0;
}

#ifdef DEBUG_STATUS
static void bq_print_status(void) {
    uint16_t vbus = bq_measure_vbus();
    int16_t ibus = bq_measure_ibus();
    uint16_t vbat = bq_measure_vbat();
    int16_t ibat = bq_measure_ibat();

    // Calculate input/output power and efficiency without using floating point arithmetic
    int32_t pin = ((int32_t)vbus * (int32_t)ibus) / 1000;  // mW
    int32_t pout = ((int32_t)vbat * (int32_t)ibat) / 1000; // mW
    if (fsc_pd_get_connection_state() == AttachedSource) {
        // OTG mode, discharging battery. pin/pout will be negative and swapped
        int32_t temp = -pin;
        pin = -pout;
        pout = temp;
    }
    uint32_t eff = 0;
    if (pin != 0 && pout != 0) {
        eff = pout * 1000 / pin; // 0..1000
    }
    debug_printf("BQ Status: %d\n", bq_get_charge_status());
    debug_printf("Vbus: %u mV, Ibus: %d mA, limit: %u mV / %u mA\n", vbus, ibus, bq_get_input_voltage_limit(), bq_get_input_current_limit());
    debug_printf("Vbat: %u mV, Ibat: %d mA\n", vbat, ibat);
    debug_printf("Pin: %ld mW, Pout: %ld mW, eff = %lu.%lu%%\n", pin, pout, eff / 10, eff % 10);
    debug_printf("BQ temperature: %d.%d C\n", bq_measure_temperature() / 2, (bq_measure_temperature() % 2) * 5);
    debug_printf("BQ thermistor: %u\n", bq_measure_thermistor());
}
#endif

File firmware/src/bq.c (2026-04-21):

#include "bq.h"
#include "debug.h"
#include <avr/io.h>
#include <util/delay.h>

#define BQ_ADDR 0x6B

static uint8_t bq_read_register(uint8_t reg);
static uint16_t bq_read_register16(uint8_t reg);
static bool bq_write_register(uint8_t reg, uint8_t value);
static bool bq_write_register16(uint8_t reg, uint16_t value);
static bool bq_set_register_bit(uint8_t reg, uint8_t bitmask, bool set);

static bool bq_read_error = false;
static volatile bool bq_interrupt_pending = false;

static uint8_t bq_read_register(uint8_t reg) {
    uint8_t data;
    if (twi_send_and_read_bytes(BQ_ADDR, reg, &data, 1)) {
        return data;
    } else {
        bq_read_error = true;
        return 0;
    }
}

static uint16_t bq_read_register16(uint8_t reg) {
    uint8_t data[2];
    if (twi_send_and_read_bytes(BQ_ADDR, reg, data, 2)) {
        return (data[0] << 8) | data[1];
    } else {
        bq_read_error = true;
        return 0;
    }
}

static bool bq_write_register(uint8_t reg, uint8_t value) {
    return twi_send_bytes(BQ_ADDR, (uint8_t[]){reg, value}, 2);
}

static bool bq_write_register16(uint8_t reg, uint16_t value) {
    return twi_send_bytes(BQ_ADDR, (uint8_t[]){reg, (value >> 8) & 0xFF, value & 0xFF}, 3);
}

static bool bq_set_register_bit(uint8_t reg, uint8_t bitmask, bool set) {
    uint8_t value = bq_read_register(reg);
    if (set) {
        value |= bitmask;
    } else {
        value &= ~bitmask;
    }
    return bq_write_register(reg, value);
}

bool bq_init(uint16_t charging_voltage_limit, uint16_t charging_current_limit) {
    bool success = true;

    // Configure BQ_INT pin
    PORTA.PIN6CTRL = PORT_INVEN_bm | PORT_PULLUPEN_bm;

    // Configure BQ_CE pin
    PORTA.DIRSET = PIN7_bm;
    PORTA.OUTSET = PIN7_bm;
    PORTA.PIN7CTRL = PORT_INVEN_bm;

    // Reset to defaults
    success &= bq_write_register(0x09, 0x45);
    if (!success) {
        return false;
    }
    _delay_ms(250);

    // Set up registers according to our needs. The comments below only reflect deviations from the POR defaults.

    // REG0A (set first as it will reset the registers below): Cell count
    uint8_t cell = 3;
    if (charging_voltage_limit >= 14000 && charging_voltage_limit <= 18800) {
        // Must set CELL = 4 for voltages above 14 V
        cell = 4;
    } else if (charging_voltage_limit < 10000) {
        // Not supported
        return false;
    }
    success &= bq_write_register(0x0A, (cell - 1) << 6 | 0x23);

    // REG00: Minimal system voltage (VSYSMIN): 9 V
    success &= bq_write_register(0x00, 0x1A);

    // REG01: Charge voltage limit (VREG)
    success &= bq_write_register16(0x01, charging_voltage_limit / 10);

    // REG03: Charge current limit (ICHG)
    success &= bq_write_register16(0x03, charging_current_limit / 10);

    // REG05: Input voltage limit (VINDPM) determined automatically from VBUS upon plugin
    
    // REG06: Input current limit (IINDPM) determined automatically via D+/D- detection

    // REG08: Use precharge current of 200 mA when battery is below 66.7% of VREG
    success &= bq_write_register(0x08, 0x85);

    // REG09: Termination current (ITERM) is set to default 200 mA (above, along with defaults reset)

    // REG0B: OTG mode regulation voltage (VOTG) is set during operation as negotiated

    // REG0D: OTG current limit (IOTG): 3 A
    success &= bq_write_register(0x0D, 0x4B);

    // REG0E: Timers are left at default values

    // REG0F: Enable ICO, start with charging disabled
    success &= bq_write_register(0x0F, 0x92);

    // REG10: Disable watchdog timer
    success &= bq_write_register(0x10, 0x00);

    // REG11: Enable automatic D+/D- detection (we will override IINDPM later if PD is used)
    success &= bq_write_register(0x11, 0x00);

    // REG11: Enable HVDCP, 9 and 12 V support
    success &= bq_write_register(0x11, 0xF8);

    // REG12: Disable BATFED LDO in pre-charge stage, as our load is not connected to SYS
    // See also: https://e2e.ti.com/support/power-management-group/power-management/f/power-management-forum/1443121/bq25792-expected-behavior-when-large-load-on-battery-causes-vbat-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
    // Also disable PFM
    success &= bq_write_register(0x12, 0x34);

    // REG13: 1.5 MHz switching frequency, disable STAT pin (not used), disable VOTG UVP hiccup mode
    success &= bq_write_register(0x13, 0x15);

    // REG14: Disable external ILIM_HIZ setting
    success &= bq_write_register(0x14, 0x14);

    // REG16: Temperature control thresholds and VBUS/VAC pulldowns: defaults

    // REG17: NTC JEITA temperature dependent charge voltage/current settings: defaults

    // REG18: NTC temperature thresholds: defaults

    // REG28: Charger Mask 0: enable AC1/AC2_PRESENT interrupt
    success &= bq_write_register(0x28, 0xF9);

    // REG29: Charger Mask 1: enable CHG interrupt
    success &= bq_write_register(0x29, 0x7F);

    // REG2A: Charger Mask 2: disable all interrupts
    success &= bq_write_register(0x2A, 0x7F);

    // REG2B: Charger Mask 3: enable temperature interrupts
    success &= bq_write_register(0x2B, 0x10);

    // REG2C: Fault Mask 0: defaults (all interrupts on)

    // REG2D: Fault Mask 1: defaults (all interrupts on)

    // Enable BQ_INT interrupts
    PORTA.PIN6CTRL |= PORT_ISC_RISING_gc;

    return success;
}

bool bq_test_connection(void) {
    uint8_t part_info = bq_read_register(0x48);
    if (bq_read_error || (part_info & 0x3F) != 0x08) {
        return false;
    }
    return true;
}

void bq_notify_interrupt(void) {
    // We can't perform an I2C write here, as we're being called from an ISR.
    // If we did, we might interfere with another ongoing I2C transaction.
    bq_interrupt_pending = true;
}

bool bq_process_interrupts(void) {
    if (!bq_interrupt_pending) {
        return false;
    }
    bq_interrupt_pending = false;
    
    uint8_t charger_flag_0 = bq_read_register(0x22);
    if (charger_flag_0 & 0x06) {
        // AC1/AC2_PRESENT changed
        return true;
    }
    uint8_t charger_flag_3 = bq_read_register(0x25);
    if (charger_flag_3 & 0x0F) {
        // TS temperature crossed
        return true;
    }

    return false;
}

bool bq_disable_charging(void) {
    return bq_set_register_bit(0x0F, 0x20, false);  // EN_CHG = 0
}

bool bq_enable_charging(void) {
    return bq_set_register_bit(0x0F, 0x20, true);  // EN_CHG = 1
}

bool bq_enable_bc12_detection(void) {
    return bq_set_register_bit(0x11, 0xC0, true);  // force detection now
}

bool bq_disable_bc12_detection(void) {
    return bq_set_register_bit(0x11, 0x40, false);
}
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

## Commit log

2025-12-03 Add info about ground connection
2025-12-03 Implement DC jack reverse polarity protection using P-channel MOSFET (closes #6)
    [kxusbc2.kicad_pcb, kxusbc2_chg.kicad_sch]
2025-12-03 Remove tooling holes; not needed anymore as we need edge rails anyway now that we have components to assemble on both sides
    [kxusbc2.kicad_pcb, kxusbc2.kicad_sch]
2025-12-04 Update silkscreen positions
    [kxusbc2.kicad_pcb]
2025-12-04 Make debug/serial pads more staggered (closes #18)
    [kxusbc2.kicad_pcb, kxusbc2_uc.kicad_sch]
2025-12-04 Clean up silkscreen label positions
    [kxusbc2.kicad_pcb]
2025-12-04 Fix RGB LED pin order
    [kxusbc2.kicad_pcb, kxusbc2_uc.kicad_sch]
2025-12-06 Implement hardware-assisted LED blinking
2025-12-08 Make LED show charging phase (CC, CV, finished) (closes #5)
2025-12-08 Reduce standby current by shutting down LED driver when not needed, and using TOG_SAVE_PWR (closes #9)
2025-12-08 Improve LED handling, tone down reaction to faults
2025-12-08 Start with LED driver shut down
2025-12-10 Revert accidental default charging voltage change. Add 100 mV headroom.
    [bq.c]
2025-12-10 Stop OTG if battery is low (closes #7)
2025-12-11 Increase via sizes where there is enough space
    [kxusbc2.kicad_pcb]
2025-12-16 Swap LED green/blue for hardware rev2
    [led.c]
2025-12-16 Add RTC calibration mode
2025-12-16 RTC calibration docs
2025-12-18 Make RTC operation independent of calibration mode
2025-12-19 Add side panel version with handles
    [side_panel_handles_s.step]
2025-12-19 Add drawing with dimensions for cutouts (for users who want to drill the original side panel)
2025-12-23 Update USER_GUIDE.md
    After upgrading the KX2 firmware from 2.69 to 3.02, the battery voltage indicator can be found under “BT”.
    This information was also posted on Elecraft KX groups.io.
    https://elecraft-kx.groups.io/g/main/topic/100601109#msg76332
2025-12-24 Add test points for I2C and interrupt lines
    [kxusbc2.kicad_pcb, kxusbc2.kicad_sch]
2025-12-25 Add photo of connected wires
2026-01-05 Reduce PCB height by 0.2 mm to improve fit (screws), and make U-shaped cutout for RF PCB screw 0.3 mm deeper (#45)
    [kxusbc2.kicad_pcb]
2026-01-05 Switch back to right-angle LED without light pipe (closes #41)
    [kxusbc2.kicad_pcb, kxusbc2_uc.kicad_sch]
2026-01-05 Adjust height on top row of receptacle pads as well
    [kxusbc2.kicad_pcb]
2026-01-05 Add JLCPCB project DB (for rotation corrections), exclude test points from BOM
    [kxusbc2.kicad_pcb, kxusbc2.kicad_sch]
2026-01-05 Move inductor slightly away from bottom edge
    [kxusbc2.kicad_pcb]
2026-01-05 Improve ground vias for SYS/PMID
    [kxusbc2.kicad_pcb]
2026-01-05 Move some parts further away from bottom edge
    [kxusbc2.kicad_pcb]
2026-01-10 Update legend, DNP
    [kxusbc2.kicad_pcb, kxusbc2.kicad_sch, kxusbc2_btmon.kicad_sch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]
2026-01-10 SYS vias
    [kxusbc2.kicad_pcb]
2026-01-11 Add production files for rev3
    [BOM-kxusbc2.csv, kxusbc2.kicad_pcb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]
2026-01-30 Add fuses programming section
2026-02-03 Add info about thermistor
2026-02-03 Add photos off standoff soldering detail
2026-02-05 Fix bogus undervoltage error after POR when ADC is not ready yet
2026-02-05 Mention direct soldering installation method
2026-02-05 Clarify harmonics of switching frequency
2026-02-12 Decrease default charging current limit to 2 A to be a bit friendlier to non high-capacity batteries (matches output current of KXBC2 external charger)
2026-02-12 Increase track widths of C3/C4. Fix JLC rotation of J1/J3/J4.
    [kxusbc2.kicad_pcb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]
2026-02-19 Clarify that heat shrink tubing is optional on white wire only
2026-02-19 Clarify that battery should be removed during installation
2026-03-02 Add LED diffuser and commentary
    [led_diffuser.step]
2026-03-03 Replace photo of stripped side panel with nicer, lasered version
2026-03-11 Add hysteresis to LED pulsing speed to avoid rapid toggling near thresholds (flickering green LED)
2026-03-16 Add a note that the battery must be connected
2026-03-18 Increase crystal load capacitors to 22p for more precise frequency pre-calibration
    [BOM-kxusbc2.csv, kxusbc2.kicad_pcb, kxusbc2_uc.kicad_sch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]
2026-04-21 Add headroom to IOTG current limit to avoid VOTG drop if load draws slightly more current than advertised (measurement inaccuracies etc.) - fixes #52
    [bq.c]
2026-04-27 Add a photo to explain how to install the board without breaking the diffuser/LED
2026-05-04 Restructure user guide (separate part for hardware assembly as most users purchase a ready-made kit)
2026-05-04 Offset LED 1 mm from edge for better mechanical protection
    [BOM-kxusbc2.csv, kxusbc2.kicad_pcb, kxusbc2.kicad_sch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]
2026-06-19 Remove schematic PDF and link to kicanvas.org instead
2026-11-10 Update diffuser for rev4 board

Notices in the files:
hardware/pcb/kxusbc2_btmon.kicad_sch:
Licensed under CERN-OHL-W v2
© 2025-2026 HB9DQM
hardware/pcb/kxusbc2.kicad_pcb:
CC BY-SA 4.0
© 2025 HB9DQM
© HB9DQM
